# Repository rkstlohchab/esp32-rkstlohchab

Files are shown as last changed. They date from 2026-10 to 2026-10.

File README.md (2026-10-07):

# esp32-rkstlohchab

ESP32-S3 N16R8 handheld wireless toolkit by **rkstlohchab**, with a TPM408-2.8 touchscreen, KY-023 joystick, Wi-Fi/BLE, and external radio, NFC, GPS and IR modules.

This repository contains the current firmware, the wiring used by this build, and the revision-2 enclosure. The firmware keeps its `ESP32-DIV/` sketch directory and internal compatibility identifiers. The visible branding is `rkstlohchab`.

## Start here

| I want to… | Open |
|---|---|
| See the wiring / final connection schematic | [Hardware guide](hardware/README.md) · [illustrated PNG](hardware/wiring-poster.png) · [zoomable SVG](hardware/wiring-poster.svg) |
| Split shared pins on a breadboard / wire direct jumpers | [Breadboard and direct wiring](hardware/BREADBOARD.md) |
| Get the component list | [Bill of materials](hardware/components.csv) |
| Look up a GPIO | [Pin map CSV](hardware/pin-map.csv) |
| Build or flash firmware | [Build and flash guide](docs/BUILD.md) |
| Download the compiled firmware | [Firmware files and checksums](firmware/README.md) |
| Print the case | [Enclosure guide](enclosure/README.md) · [download ZIP](enclosure/enclosure-v2.zip) |
| Explore the 3D assembly | [Interactive viewer](enclosure/enclosure.html) · [layout drawing](enclosure/layout-v2.png) |
| Avoid the assembly mistakes we encountered | [Mistakes and fixes, including PN532 mode switches](docs/ASSEMBLY-MISTAKES.md) |
| Check what has actually been tested | [Status and limitations](docs/STATUS.md) |
| Find the source | [Arduino sketch](ESP32-DIV/ESP32-DIV.ino) · [board pin configuration](ESP32-DIV/BoardConfig.h) |
| Apply the required display patches | [TFT_eSPI patch](tft_espi-patch/README.md) |

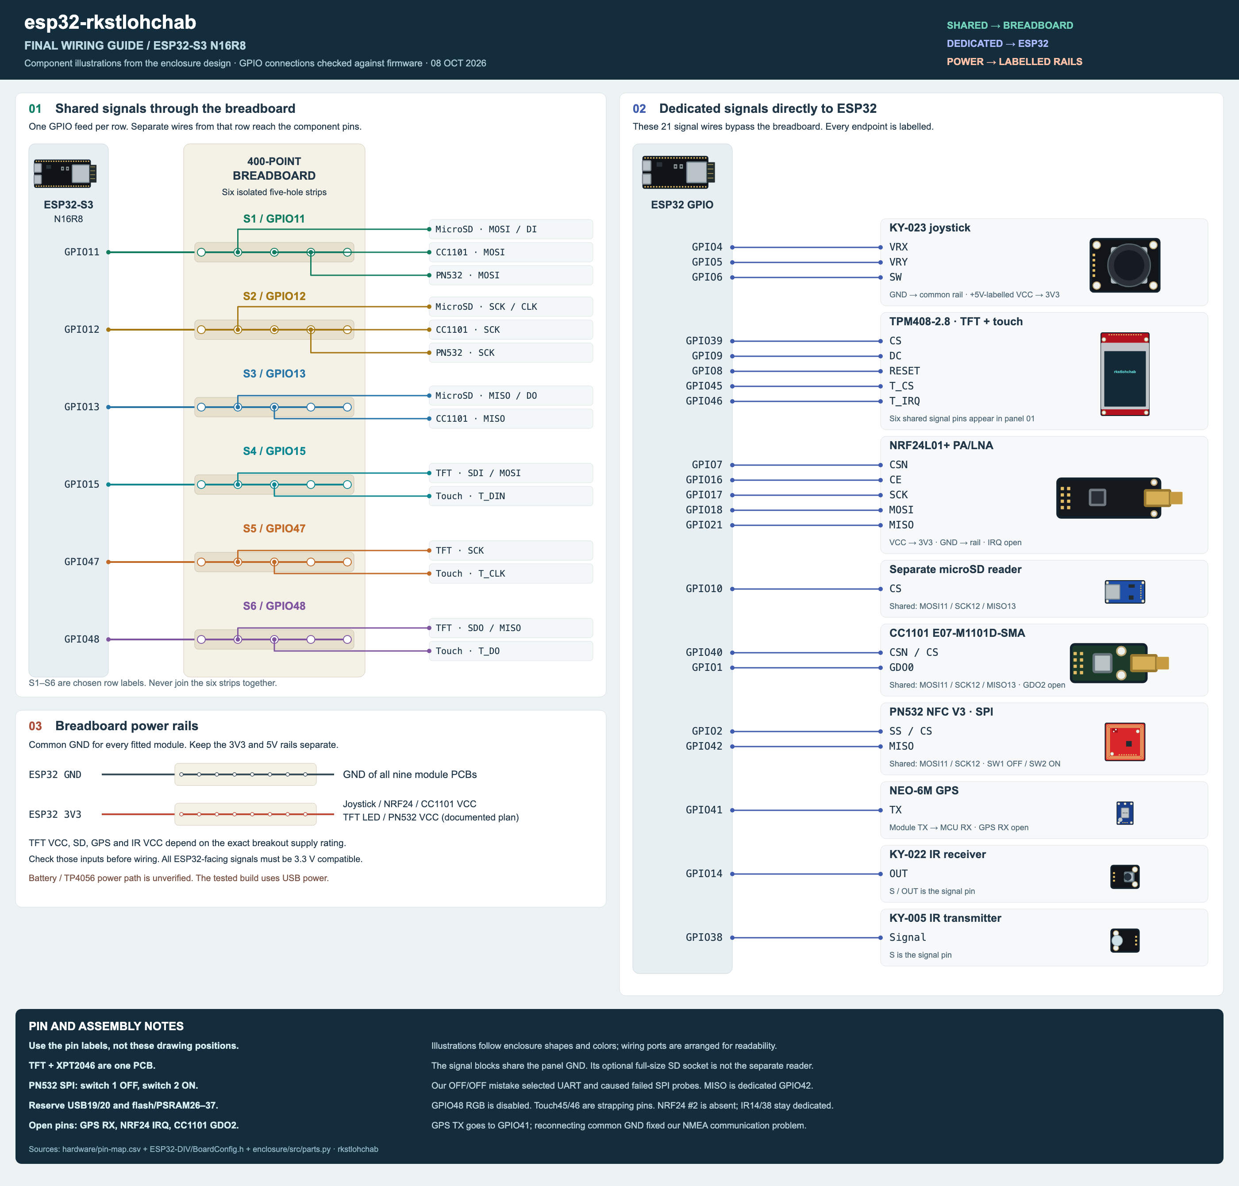
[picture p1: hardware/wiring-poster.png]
Illustrated wiring guide: shared breadboard nets and direct ESP32 pins


[Download full-resolution PNG](hardware/wiring-poster.png) · [Zoomable SVG](hardware/wiring-poster.svg) · [Detailed connection schematic](hardware/wiring.svg)

## Use the device

1. Wire the board using the [current hardware guide](hardware/README.md).
2. Flash the N16R8 firmware using the [build and flash guide](docs/BUILD.md).
3. Boot normally for the primary UI. Hold the joystick click while resetting, then release, for the alternate full-screen UI. Restart to switch modes.
4. Use the joystick to navigate; touch calibration is available in the primary UI.

The latest branded build compiles at **2,724,621 bytes (86% of the 3 MB app slot)** and **159,604 bytes of static RAM (48%)**. It has not been flashed or hardware-tested in this documentation update. Earlier hardware results are recorded separately in [status](docs/STATUS.md).

## 3D enclosure

Revision 2 is **96.4 × 168.4 × 94.0 mm** (width × height × depth), excluding antennas and joystick projection. It includes clearance for breadboard jumper housings and loose wire bays.

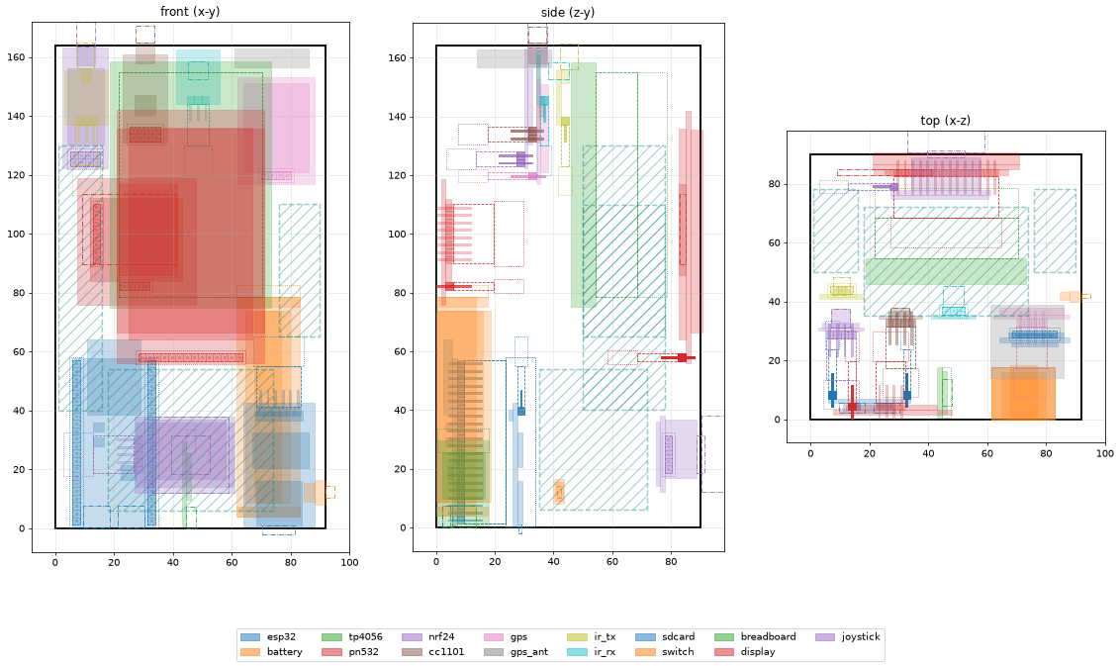
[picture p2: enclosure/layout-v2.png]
Revision-2 enclosure layout


- [Back tub STL](enclosure/stl/enclosure_back_tub.stl)
- [Front plate STL](enclosure/stl/enclosure_front_plate.stl)
- [Parametric source and rebuild instructions](enclosure/README.md)

The enclosure passes digital collision and solid checks; it has **not been physically print-tested**. Battery/charger/switch pockets are mechanical provisions. The verified electrical build runs on USB with the battery circuit disconnected.

## Repository map

```text
ESP32-DIV/          Arduino firmware and board-specific GPIO configuration
hardware/           Current wiring, component list, pin map and diagram generator
enclosure/          Revision-2 STL files, 3D viewer, layout and parametric source
firmware/           Current N16R8 binaries and SHA-256 checksums
docs/               Build guide, status and local documentation entry page
tft_espi-patch/     Required TPM408 display configuration and rotation patch
Libraries/          Upstream library archives; see build guide before using
PCB/, Schematic/   Legacy upstream PCB designs, not this breadboard build
licenses/           Notices for incorporated third-party code
```

The files `PORT.md`, `MERGE.md`, and `MARAUDER-UI-FIX.md` are historical development notes. Start with the current guides above: older notes contain earlier pin assignments and build sizes. Legacy bundled binaries and the old upstream web flasher are excluded from this clean repository snapshot.

## License and acknowledgments

This project incorporates ESP32-DIV and ESP32 Marauder code. Required upstream MIT notices are preserved in [LICENSE](LICENSE) and [licenses/ESP32Marauder-MIT.txt](licenses/ESP32Marauder-MIT.txt). Branding changes do not change those notices. Use wireless testing features only on equipment and networks you own or have permission to test.

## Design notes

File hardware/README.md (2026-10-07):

# Current hardware and wiring

Snapshot: **2026-10-08**. Electrical pin assignments come from [`ESP32-DIV/BoardConfig.h`](../ESP32-DIV/BoardConfig.h), checked against the configured display patch and the latest local bring-up notes. This is the final documented **module connection schematic for the current bench configuration**, not a new custom PCB design.

- [Illustrated wiring image (PNG)](wiring-poster.png) · [zoomable SVG](wiring-poster.svg)
- [Detailed connection schematic](wiring.svg)
- [Breadboard shared rows and direct jumpers](BREADBOARD.md)
- [Machine-readable pin map](pin-map.csv)
- [Component list / bill of materials](components.csv)
- [3D enclosure and assembly](../enclosure/README.md)
- [Verification record](../docs/STATUS.md)

Illustrated wiring guide

## Signal connections

| Module | Module pins → ESP32-S3 GPIO |
|---|---|
| KY-023 joystick | VRX → 4; VRY → 5; SW → 6 |
| ILI9341 TFT | SDI/MOSI → 15; SCK → 47; SDO/MISO → 48; CS → 39; DC → 9; RESET → 8 |
| XPT2046 touch | T_DIN → 15; T_CLK → 47; T_DO → 48; T_CS → 45; T_IRQ → 46 |
| NRF24L01+ (one radio) | CSN → 7; CE → 16; SCK → 17; MOSI → 18; MISO → 21; IRQ unconnected |
| Separate microSD reader | CS → 10; MOSI/DI → 11; SCK/CLK → 12; MISO/DO → 13 |
| CC1101 | CS → 40; MOSI → 11; SCK → 12; MISO → 13; GDO0 → 1; GDO2 unconnected |
| PN532 in SPI mode | SS/CS → 2; MOSI → 11; SCK → 12; MISO → 42; SDA/SCL not used |
| GPS NEO-6M | TX → 41; RX unconnected; UART 9600 baud |
| IR receiver | OUT → 14 |
| IR transmitter | Signal → 38 |

Touch IRQ is wired but touch is polled. The GPS TX output connects to the MCU's RX input; `GPS_UART_TX=0` is an unused firmware placeholder, **not a connection to make**. Likewise, `CC1101_GDO2=1` is a software alias for the single GDO0 data path; it does not mean physically join GDO2 to GPIO1.

## SPI wiring groups

| Group | SCK | MOSI | MISO | Individual selects |
|---|---|---|---|---|
| Display + touch | 47 | 15 | 48 | TFT 39; touch 45 |
| Storage / SubGHz | 12 | 11 | 13 | SD 10; CC1101 40 |
| PN532 software SPI | 12 (shared) | 11 (shared) | **42 (dedicated)** | PN532 2 |
| NRF24 wiring | 17 | 18 | 21 | CSN 7; CE 16 |

These are wiring groups, not a claim of four independent hardware SPI controllers. Firmware reclaims shared SPI resources when changing features. Never join PN532 MISO42 to the storage MISO13 net. Modules sharing clock/MOSI need their own chip selects, with inactive devices deselected.

## Power connections

The current tested build is **USB powered**. Distribute supply and GND using breadboard rails; all module grounds connect to ESP32 GND.

| Module | Power connection / constraint |
|---|---|
| Joystick | VCC pin marked `+5V` is connected to **3V3** so VRX/VRY stay within ESP32 input levels |
| TFT backlight LED | **3V3**, hardwired; no MCU backlight PWM pin |
| NRF24L01+ | **3V3 only**; 10–47 µF capacitor close to VCC/GND |
| CC1101 | **3V3**, with common GND |
| PN532 V3 | 3V3 supply in the documented plan; SPI switch mode on the tested module: SW1 OFF, SW2 ON |
| TFT module VCC, SD reader, GPS, IR modules | Check the exact breakout's regulator and supply rating. All MCU-facing signals must be 3.3 V compatible. The notes do not establish one universal VCC for every breakout variant |

The SD reader's VCC depends on its regulator and level shifting; use 5 V only for a breakout designed for that input. A bare 3.3 V card interface needs 3V3. Do not infer VCC from the signal wiring diagram.

The 18650, TP4056 and power switch are present in the **mechanical** design but were disconnected in the latest electrical checks. There is no verified battery-to-ESP32 regulated power schematic in this project. Do not connect a Li-ion cell directly to 3V3 or assume the case's battery pocket defines a complete power circuit.

## Pins intentionally unavailable or unconnected

- GPIO19/20 are reserved for native USB.
- GPIO26–32 and GPIO33–37 are reserved by flash and octal PSRAM on this N16R8 configuration.
- GPIO48 is display MISO; firmware disables the onboard RGB LED.
- GPIO0 is BOOT; leave GPS RX disconnected rather than wiring the unused TX placeholder.
- GPIO45/46 are boot strapping pins used by this existing touch wiring. Preserve the tested reset levels; do not treat them as generic extra outputs.
- NRF24 radios #2/#3, buzzer, PCF8574, and battery ADC are not fitted/enabled. NRF24 #2 placeholders overlap IR14/38 and must be reassigned before adding that radio.
- NRF24 IRQ and CC1101 GDO2 remain open.

GPIO numbers are signal labels, not physical header positions. Match the printed GPIO labels on your exact DevKit board. Legacy `PCB/` and `Schematic/` files describe upstream boards and do not override this pin map.

## Rebuild the pin diagram

```sh
python3 hardware/generate_wiring.py
```

The generator reads `pin-map.csv`, checks every GPIO against the board configuration, and writes `wiring.svg`. Update the firmware configuration and CSV together when wiring changes.

See [assembly mistakes and fixes](../docs/ASSEMBLY-MISTAKES.md), especially the PN532 mode switches and GPS common ground.

## Illustrated image and component models

The [final PNG](wiring-poster.png) combines component illustrations derived from `enclosure/src/parts.py` with the verified CSV connections. Its left panel shows six ESP32 feeds into six breadboard strips and individual component branches. Its right panel shows all 21 dedicated signal connections. They describe the same ESP32 and modules, separated into two panels for readable wire paths.

Module illustrations identify the parts and their proportions. Wires terminate at labelled schematic ports; follow your actual PCB silkscreen rather than treating illustration positions as a header locator. TFT and touch share one physical PCB. Power inputs whose breakout supply rating has not been established are explicitly marked for verification.

Regenerate both formats (PNG export requires Chrome/Chromium):

```sh
python3 hardware/generate_wiring_poster.py --png
```

Omit `--png` to regenerate the editable SVG without a browser.

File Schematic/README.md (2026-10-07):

# Legacy upstream Schematic files

These assets are retained as design references for the original upstream boards. They are **not the final schematic or PCB for this ESP32-S3 N16R8 breadboard build**.

Use the [current hardware wiring](../hardware/README.md), [pin map](../hardware/pin-map.csv), and [revision-2 enclosure](../enclosure/README.md).

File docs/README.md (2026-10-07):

# Documentation

- [Final illustrated wiring image](../hardware/wiring-poster.png) · [zoomable version](../hardware/wiring-poster.svg)
- [Current hardware schematic and connections](../hardware/README.md)
- [Breadboard shared pins and direct ESP32 jumpers](../hardware/BREADBOARD.md)
- [Component list](../hardware/components.csv)
- [GPIO pin map](../hardware/pin-map.csv)
- [Build and flash](BUILD.md)
- [Verification and limitations](STATUS.md)
- [3D design, assembly and printing](../enclosure/README.md)
- [Firmware downloads](../firmware/README.md)

To open the interactive 3D assembly, run `python3 -m http.server 8000` from the repository root and visit `http://localhost:8000/enclosure/enclosure.html`. The viewer currently loads Three.js and fonts from CDNs, so internet access is needed. GitHub's file preview displays the HTML source rather than running the viewer.

`PORT.md`, `MERGE.md`, and `MARAUDER-UI-FIX.md` at the repository root are retained as historical notes, not the current wiring reference.

See [assembly mistakes and fixes](../docs/ASSEMBLY-MISTAKES.md), especially the PN532 mode switches and GPS common ground.

The interactive enclosure HTML is committed under `enclosure/enclosure.html`. GitHub Pages is not configured; the repository file link shows source, and the local server instructions above run the viewer.

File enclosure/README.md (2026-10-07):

# Enclosure revision 2 — jumper wire space

**Outer size: 96.4 × 168.4 × 94.0 mm (width × height × depth).**
Internal cavity: 92 × 164 × 90 mm. Previous case: 62.4 × 128.4 × 66 mm.
Dimensions exclude antennas and the projecting joystick cap.

This revision retains the 400-point breadboard and allows Dupont connectors
on all header modules, including NRF24, CC1101, GPS and IR. The original
solder-only assumption for those modules has been removed. This repository distributes revision 2 only.

## Files

| File | Use |
|---|---|
| `stl/enclosure_back_tub.stl` | Print back down; support the SD shelf above the battery |
| `stl/enclosure_front_plate.stl` | Print face down |
| `enclosure.html` | Interactive assembly, exploded view, drawings and STL downloads |
| `layout-v2.png` | Orthographic views; hatched areas reserve loose wire space |
| `layout.json` | Dimensions, placements, openings and wire budget |
| `build.py`, `src/` | Parametric design and clearance checks |

## Space for your wires

The design assumes **60 individual 20 cm wires plus five individual 40 cm
wires**, with insulation up to 2 mm diameter: 14 metres total.
At 30% wire / 70% free air, the estimated loose-wire volume is **146.6 cm³**.
Three dedicated bays provide **154.9 cm³**, in addition to connector and bend
envelopes. This is a packing estimate, not a simulated routed harness;
thicker wires, ribbon bundles or extra modules need more space.

| Reserved region | Clear size | Volume |
|---|---|---|
| Lower service-loop bay | 56 × 48 × 37 mm | 99.5 cm³ |
| Left routing corridor | 15 × 90 × 28 mm | 37.8 cm³ |
| Right routing corridor | 14 × 45 × 28 mm | 17.6 cm³ |

Each header allows **14 mm female housings plus 10 mm free space after the
housing**. Straight connectors also include their male header spacer.
The breadboard has a 24 mm plug-and-bend zone above its 8.5 mm body.
The PN532 model reserves both header banks, including SPI.

Put surplus wire into broad, loose loops in the lower bay. Use the side
corridors for front connections. Keep the lid lip, screws, joystick mechanism,
display glass and GPS patch clear. Fit module plugs before installing the
breadboard. Leave service slack for lifting the front plate. The lid should
seat freely; its screws must not compress wire bundles.

## Battery pocket: 4 mm longer

Nominal holder: 74.5 × 21.5 mm. Cell: 65 mm long, unchanged.
The end stop moves **4.0 mm**, giving **78.9 mm clear length**
(74.5 + 4.0 + 0.4 mm fit allowance). Two side rails give **21.9 mm clear width**.
The extra length is reserved in the collision model. Add a removable foam
shim if the existing shorter holder slides.

## Layout and ports

Breadboard underside: 46 mm above the inside back face. Jumper bend space
ends at 78.5 mm. Display PCB: 85 mm. The lower section holds the wire loops.
The display and joystick are centred on the removable front plate.

USB-C and microSD access remain on the bottom; SMA and IR openings are on top;
the switch is on the right. The back has the NFC target and BOOT/RST pinholes.
Use the **separate microSD reader**: the display's optional full-size SD socket
is now internal only.

PN532 uses SPI: switch 1 away from ON, switch 2 toward ON.
SCK → GPIO12, MOSI → GPIO11, MISO → GPIO42, SS → GPIO2.
SDA/SCL are not used in this mode. Viewer colors are suggested labels,
not a record of installed wire colors.

## Printing and assembly

Starting settings: 0.4 mm nozzle, 0.20 mm layers, 4 perimeters, 25% infill,
PLA or PETG. Inspect the slicer preview. The back tub's broad SD shelf needs
removable support beneath it; remove support before fitting the battery.
Other overhangs depend on your printer. STLs are already oriented on z=0.

Hardware: 4 × M2.5 × 8 countersunk lid screws, 4 × M3 × 6 display screws,
2 × M3 × 8 joystick screws, removable tape/foam for parts without screw mounts.
Print the front plate first to check the display and joystick fit.

1. Remove supports. Fit ESP32. Fit the TP4056 and holder mechanically if desired; keep the unverified battery circuit disconnected.
2. Fit PN532 on its pegs, GPS on its posts and patch beneath the top wall.
3. Fit radios, IR boards, microSD and switch. Connect their jumpers.
   Tape/foam secures boards without dedicated screw mounts.
4. Tape the breadboard onto its side ledges. Arrange loose wires in the lower
   bay and side corridors before fitting front connections.
5. Mount display and joystick on the plate, connect them, and lower the plate
   while watching the wiring. Close with four lid screws only when it seats freely.

## Verification and limits

The build rejects module/wall conflicts, printed solids blocking modules,
connectors, bends or reserved wire bays, shell mating interference, and
insufficient wire volume. PN532/GPS mounting holes are excluded from their
coarse boxes so the pegs can pass through. Both meshes must be valid connected
solids. Revision 2 passes these checks with **zero conflicts**.

This is digitally checked, not physically print-tested. Joystick and IR sizes
include estimates; several modules use listing dimensions and photo-derived
positions. Check your board variants, connector heights and holder dimensions.
The design includes the 15 parts listed in `layout.json`. A separate boost
converter has no dedicated mount or assumed footprint in this revision.

## Rebuild

```sh
pip install manifold3d numpy matplotlib
python3 build.py
python3 src/layout.py layout-v2.png
```

Parts: `src/parts.py`; placements and wire budget: `src/layout.py`;
printed mounts: `src/shell.py`. Rebuilding updates the STLs and viewer together.

## Electrical reference

Use the [current hardware guide](../hardware/README.md) for electrical connections. Battery, charger and switch models are mechanical provisions; the verified build is USB powered.

The [illustrated wiring guide](../hardware/wiring-poster.png) uses these component models together with the firmware pin map. See the [editable wiring SVG](../hardware/wiring-poster.svg) for a zoomable version.

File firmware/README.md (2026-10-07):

# Current N16R8 firmware

Built 2026-10-08 from the branded source in this snapshot, using ESP32 core 2.0.10 and the settings in the [build guide](../docs/BUILD.md).

| File | Flash offset | Purpose |
|---|---|---|
| [ESP32-DIV.ino.bootloader.bin](ESP32-DIV.ino.bootloader.bin) | 0x0000 | ESP32-S3 bootloader |
| [ESP32-DIV.ino.partitions.bin](ESP32-DIV.ino.partitions.bin) | 0x8000 | 16 MB flash partition table, two 3 MB app slots |
| [boot_app0.bin](boot_app0.bin) | 0xe000 | Initial OTA selection data |
| [ESP32-DIV.ino.bin](ESP32-DIV.ino.bin) | 0x10000 | Application |

[SHA-256 checksums](SHA256SUMS.txt). Verify from this directory with `shasum -a 256 -c SHA256SUMS.txt` (macOS) or `sha256sum -c SHA256SUMS.txt` (Linux).

Application: 2,724,621 bytes (86% of slot). Static RAM: 159,604 bytes (48%). Compile and a host frame-bounds check passed; this exact branded snapshot has **not been flashed or hardware-tested**. These binaries target the documented N16R8 configuration, not stock ESP32-DIV PCB variants.

See the [complete flash command](../docs/BUILD.md#flash-precompiled-binaries); the application binary alone is not the first-flash package.

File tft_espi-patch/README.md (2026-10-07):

# TFT_eSPI patch for this build

The firmware only displays correctly with these two files dropped into the
Arduino **TFT_eSPI 2.5.43** library (`~/Documents/Arduino/libraries/TFT_eSPI/`),
overwriting the originals:

| File | Why |
|---|---|
| `User_Setup.h` | Pins for the dedicated display bus (MOSI 15, SCLK 47, MISO 48, CS 39, DC 9, RST 8, touch CS 45), `ILI9341_NATIVE_LANDSCAPE_PANEL`, and `TFT_RGB_ORDER TFT_RGB` |
| `TFT_Drivers/ILI9341_Rotation.h` | Axis-swapped rotations for the TPM408-2.8 panel, whose glass is scanned 320x240 |

Without them the UI draws rotated 90° with 80 rows of noise, and red/blue are
swapped. After copying, delete the build cache's `libraries/TFT_eSPI` folder
so the headers are recompiled.

Re-apply after any TFT_eSPI update or reinstall.

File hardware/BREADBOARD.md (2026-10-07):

# Breadboard sharing and direct ESP32 jumpers

Use this alongside the [complete pin diagram with actual ESP32 → breadboard → component paths](wiring.svg) and [hardware power notes](README.md#power-connections). The firmware determines which wires share a net; the breadboard rows below are a suggested physical layout, not a record of exact numbered rows in the assembled prototype.

## Shared signal pins: split these on the breadboard

Run **one jumper from the ESP32 GPIO to its own connected five-hole breadboard row**, then connect each listed module pin to that same row. Use a different isolated row for each GPIO. On a typical breadboard, the two five-hole groups on opposite sides of the centre gap are not connected. Bridge only if you deliberately need the other side.

| Suggested isolated row | ESP32 GPIO → row | Module pins connected to that same row |
|---|---|---|
| S1 | GPIO**11** | MicroSD **MOSI / DI**; CC1101 **MOSI**; PN532 **MOSI** |
| S2 | GPIO**12** | MicroSD **SCK / CLK**; CC1101 **SCK**; PN532 **SCK** |
| S3 | GPIO**13** | MicroSD **MISO / DO**; CC1101 **MISO** |
| S4 | GPIO**15** | TFT ILI9341 **SDI / MOSI**; Touch XPT2046 **T_DIN** |
| S5 | GPIO**47** | TFT ILI9341 **SCK**; Touch XPT2046 **T_CLK** |
| S6 | GPIO**48** | TFT ILI9341 **SDO / MISO**; Touch XPT2046 **T_DO** |

S1–S6 are labels you choose, not mandatory printed row numbers. Each is an independent electrical net. Keep signal wires short, especially SPI clock and data.

Shared breadboard nets

**Do not combine all MOSI or all MISO pins into one row.** Display MOSI15 and storage MOSI11 are separate nets; display MISO48, storage MISO13, PN532 MISO42 and NRF24 MISO21 are all separate. NRF24 SCK17/MOSI18/MISO21 each go only to that radio in this build.

## Dedicated signals: one direct jumper to the ESP32

These have one module endpoint in the current fitted configuration. They can connect directly to the GPIO-labelled ESP32 header, without a breadboard split. Routing one through an isolated breadboard row is electrically equivalent if it makes assembly easier.

| Module | Direct ESP32 GPIO ↔ module pin |
|---|---|
| Joystick | GPIO**4** ↔ **VRX**; GPIO**5** ↔ **VRY**; GPIO**6** ↔ **SW** |
| TFT ILI9341 | GPIO**39** ↔ **CS**; GPIO**9** ↔ **DC**; GPIO**8** ↔ **RESET** |
| Touch XPT2046 | GPIO**45** ↔ **T_CS**; GPIO**46** ↔ **T_IRQ** |
| NRF24L01+ | GPIO**7** ↔ **CSN**; GPIO**16** ↔ **CE**; GPIO**17** ↔ **SCK**; GPIO**18** ↔ **MOSI**; GPIO**21** ↔ **MISO** |
| MicroSD | GPIO**10** ↔ **CS** |
| CC1101 | GPIO**40** ↔ **CS**; GPIO**1** ↔ **GDO0** |
| PN532 | GPIO**2** ↔ **SS / CS**; GPIO**42** ↔ **MISO** |
| GPS NEO-6M | GPIO**41** ↔ **TX** |
| IR receiver | GPIO**14** ↔ **OUT** |
| IR transmitter | GPIO**38** ↔ **Signal** |

The KY-023 VRX4/VRY5/SW6 connections are documented as direct to the ESP32 in the existing build notes. For the other dedicated signals, this table describes the direct jumper wiring supported by the current pin assignments; the notes do not establish every jumper's actual physical routing.

GPIO45/46 are strapping pins in the tested touch wiring; preserve the current reset levels. IR14/38 are dedicated only while NRF24 #2 is absent. Do not install the second radio on those placeholder assignments.

## Power: use the common breadboard rails

- ESP32 **GND → ground rail**; each fitted module's GND → that same rail.
- ESP32 **3V3 → a labelled 3V3 rail**; connect only modules/inputs requiring 3.3 V to it. Joystick `+5V` silkscreen is supplied from **3V3** in this build.
- TFT backlight LED → 3V3 rail. NRF24 VCC → 3V3 rail, with its capacitor directly across local VCC/GND.
- If an exact breakout needs a 5 V input, use a separate labelled **5 V rail** after checking its rating and signal compatibility. **Never bridge 3V3 and 5 V rails.** See [module-specific supply constraints](README.md#power-connections).
- Many breadboard power rails are split halfway along their length. Check continuity and bridge matching rail segments only when needed.

Power off before changing jumpers. Do not push multiple Dupont connectors onto one ESP32 header pin; split shared nets on the breadboard instead. The battery circuit stays disconnected until a regulated power path has been specified and tested.

## Leave these unconnected

NRF24 IRQ, CC1101 GDO2, GPS RX, all unfitted second/third radio connections, and disabled buzzer/battery-ADC placeholders. All module grounds still need the common GND rail.

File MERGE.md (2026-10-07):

# ESP32-DIV + Marauder — merged firmware

A copy of the ESP32-DIV N16R8 port (`esp32-div/`) with **ESP32Marauder embedded as
a headless serial-CLI subsystem**. DIV keeps its full display UI and its own features
(WiFi/BLE UI, SubGHz, NFC, IR, GPS); Marauder adds its deeper WiFi/BLE/GPS engine,
reachable over the USB serial CLI.

**Status: FULL-UI merge — compiles (71%), normal boot verified on hardware (2026-09-21).**
Marauder now runs with its COMPLETE native touch UI (116 screens), not a CLI.
DIV boots clean (banner, SD, BLE init, PCF/joystick nav, no crash, single boot).
Marauder CLI is live over serial: `help` returns the full command set, and a real
`scanall` found local APs with RSSI/channel/BSSID *and* station-to-AP relationships;
`stopscan` and `list -a` work. No panics or boot loops.

- Merged app size: **2,239,885 bytes (71%** of a 3 MB app partition, full UI)
- RAM: 155,572 bytes static (47%)
- **Zero symbol collisions** between the two codebases.

## How the merge works

The blocker with a "real" merge is that Marauder's WiFi engine (`WiFiScan.cpp`,
12,789 lines) has **923 references to Marauder's own `Display` object** — its engine
is inseparable from its UI. Merging two display UIs onto one screen is not feasible.

The solution: Marauder's own full touch UI is re-enabled by targeting its
`MARAUDER_MULTIBOARD_S3` board (an ESP32-S3 + ILI9341) and grafting the ILI9341
320x240 UI-layout constants (from Marauder's `MARAUDER_V4` blocks) onto it, since the
stock S3 target ships headless. Both DIV and Marauder drive the SAME ILI9341 through
TFT_eSPI's one `User_Setup.h`, and both read touch via `tft.getTouch()` — so they
share the display + touch layer cleanly.

**Two modes, selected at boot** (no dual-UI-on-one-screen conflict):
- Normal power-on -> **ESP32-DIV** (its UI + SubGHz/NFC/IR + its own WiFi/BLE).
- **Hold the joystick click at power-on -> Marauder's full touch UI** (all 116
  screens: WiFi/BLE attacks, scans, evil portal, wardrive, etc.). Reboot to switch.

The engine lives under `ESP32-DIV/src/marauder/`; `marauder_setup()/marauder_loop()`
are invoked exclusively when the joystick launches Marauder mode.

## What was changed (all in the copy, originals untouched)

1. **`ESP32-DIV/src/marauder/`** — all 83 Marauder source files, plus:
   - `configs.h`: `#define GENERIC_ESP32` enabled (headless: WiFi + BT, no screen)
   - `marauder_app.cpp`: Marauder's `.ino`, with `setup()/loop()` renamed to
     `marauder_setup()/marauder_loop()`, and the `while(!Serial)` boot-wait bounded
     to 1.5 s so it never blocks on battery.
   - `marauder_app.h`: exposes those two entry points.
2. **`ESP32-DIV/ESP32-DIV.ino`** — includes `src/marauder/marauder_app.h`, calls
   `marauder_setup()` at the end of `setup()` and `marauder_loop()` at the top of
   `loop()`. So Marauder's CLI runs alongside DIV's UI.
3. **Partition scheme → Huge APP (3 MB + 1 MB SPIFFS), no OTA.** Marauder stores its
   settings in **SPIFFS**, which the FAT partition scheme lacks. Huge APP provides
   SPIFFS and still fits the 2 MB merged app. (Trade-off: no OTA on this build.)

## Build settings (Arduino IDE)

Same as the DIV port EXCEPT the partition scheme:

| Setting | Value |
|---|---|
| Board | ESP32S3 Dev Module |
| PSRAM | OPI PSRAM |
| Flash Size | 16MB (128Mb) |
| **Partition Scheme** | **Huge APP (3MB No OTA/1MB SPIFFS)** |
| USB CDC On Boot | Enabled |
| Flash Mode | QIO 80MHz |
| CPU | 240MHz |

FQBN: `esp32:esp32:esp32s3:PSRAM=opi,FlashSize=16M,PartitionScheme=huge_app,CDCOnBoot=cdc,FlashMode=qio,CPUFreq=240,USBMode=hwcdc`

## Libraries added for Marauder (DIV's shared deps kept per instruction)

Installed alongside DIV's set; where shared (NimBLE, TFT_eSPI, ArduinoJson) DIV's
versions were kept:

| Library | Version | For |
|---|---|---|
| LinkedList | (Marauder submodule) | Marauder data structures |
| Adafruit NeoPixel | 1.15.5 | LED (guarded off headless) |
| MicroNMEA | 2.0.6 | GPS parsing |
| EspSoftwareSerial | 8.1.0 | GPS soft-serial |
| ESP32Ping | (github marian-craciunescu) | network ping scan |
| Async TCP | 3.5.0 | Evil Portal async server |
| ESP Async WebServer | 3.12.1 | Evil Portal |

Note: Async TCP 3.x and ESP Async WebServer 3.x MUST be paired (the old me-no-dev
1.1.4 AsyncTCP fails to compile against WebServer 3.x).

## How to use once flashed

- **DIV's UI** works as before on the display (needs the 2.8" ILI9341).
- **Marauder's CLI** is live over USB serial at 115200. Open the Serial Monitor and
  type `help` for the full command list — `scanall`, `attack -t deauth`, `sniffraw`,
  `blespam`, `evilportal`, `wardrive`, `list`, `select`, etc.

## Verified on hardware / remaining caveats

Resolved by the boot+scan test: boots clean, Marauder WiFi engine actually scans, no
crash. Still worth knowing:
1. **Double WiFi init** — both DIV and Marauder init WiFi. Should be fine if only one
   drives the radio at a time, but a DIV WiFi feature + a Marauder scan at once could
   conflict.
2. **RAM under load** — 47% static; running a heavy Marauder scan *and* DIV together
   could get tight.
3. **Serial contention** — DIV's "Serial Monitor" tool and Marauder's CLI both read
   serial; avoid using both at once.
4. **Boot time** — `marauder_setup()` adds WiFi + SPIFFS init before DIV's UI appears.

If any of these misbehave, the fallback is **lazy activation**: gate `marauder_setup()`
behind a DIV menu entry so Marauder only initializes when you enter its mode.

## Revert

This whole thing is a copy — `esp32-div/` (DIV-only) is untouched. Delete
`esp32-div-marauder/` to discard the merge entirely.

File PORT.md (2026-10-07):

# ESP32-DIV — port to ESP32-S3 DevKitC-1 N16R8

Upstream ESP32-DIV **V2** targets an **ESP32-S3-WROOM-1U-N16** (confirmed in
`Schematic/v2/main-BOM.xls`): 16 MB flash, **no PSRAM**. With no PSRAM die in the
module, GPIO 33–37 are free, so upstream routes the display + touch bus there.

This board is an **ESP32-S3 N16R8**: 16 MB flash **plus 8 MB octal PSRAM**. Octal
PSRAM is bonded to GPIO 33–37 *inside the module*, so those pins cannot be used as
GPIO while PSRAM is enabled. The port moves the display bus off those pins and keeps
the full 8 MB PSRAM.

**Status: RUNNING on hardware with display + touch + joystick (2026-09-24).** The
TPM408-2.8 panel renders portrait, touch is calibrated, and the joystick drives the
menus. Firmware ~2.76 MB (87% of the 3 MB app partition) with the built-in IR
database. Display wiring and quirks are documented in `tft_espi-patch/` and the
project memory; see the pin map below for the current schema.

---

## Build settings (Arduino IDE)

Board: **ESP32S3 Dev Module**

| Setting | Value |
|---|---|
| USB CDC On Boot | **Enabled** — the DevKit has no CP2102; serial rides native USB |
| PSRAM | **OPI PSRAM** |
| Flash Size | 16MB (128Mb) |
| Flash Mode | QIO 80MHz |
| Partition Scheme | 16M Flash (3MB APP/9.9MB FATFS) |
| CPU Frequency | 240MHz |
| Upload Speed | 921600 |
| USB Mode | Hardware CDC and JTAG |

Open `esp32-div/ESP32-DIV/ESP32-DIV.ino`. `BoardConfig.h` already selects this board.

Verified via arduino-cli with:
`esp32:esp32:esp32s3:PSRAM=opi,FlashSize=16M,PartitionScheme=app3M_fat9M_16MB,CDCOnBoot=cdc,FlashMode=qio,CPUFreq=240,USBMode=hwcdc`

---

## What was changed, and why

The design goal was **all board differences in one place**. Every pin in
`shared.h` is `#ifndef`-guarded, so `BoardConfig.h` overrides them without touching
upstream sources. Upstream files carry only two tiny, marked edits; every original
is saved next to it as `.upstream`/`.orig`/`.stock`.

### 1. `ESP32-DIV/BoardConfig.h` — rewritten (upstream saved as `.upstream`)
The whole port lives here: joystick nav, moved display/touch bus, verified NRF24
pins, PN532-over-SPI, and placeholder pins for unfitted modules. Fully commented.

### 2. `ESP32-DIV/NavInput.h` — new
`JoystickNav` implements the three methods the feature code calls on the PCF8574
(`begin` / `pinMode` / `digitalRead`) and maps the 5-way keypad onto the KY-023's
two ADC axes + click. `typedef … NavExpander` picks joystick or real PCF8574. No
feature file changes; the object is still called `pcf`.

### 3. `ESP32-DIV/shared.h` — 3 marked edits (upstream saved as `.upstream`)
- `#include "NavInput.h"` after `BoardConfig.h`.
- `SD_NO_CARD_DETECT` guard so a card-detect-less breakout skips the `SD_CD` read.
- `TFT_CS_PIN` / `TFT_DC_PIN` / `TFT_RST_PIN` made overridable.

### 4. `pcf` object type: `PCF8574` → `NavExpander`
Six declaration sites (`bleconfig.h`, `config.h`, `wificonfig.h`, `subconfig.h`,
`ducky.cpp`, `ESP32-DIV.ino`). `ESP32-DIV.ino` also guards `#include <PCF8574.h>`.

### 5. `TFT_eSPI/User_Setup.h` — display pins + speed (stock saved as `.div-v2-stock`)
MISO/MOSI/SCLK → the shared SD bus (13/11/12); CS/DC/RST → 39/40/41;
`SPI_FREQUENCY` 27 MHz → 20 MHz (those pins have the parasitic PSRAM die on them).

### 6. `SmartRC-CC1101-Driver-Lib` — two library bugs
- `ELECHOUSE_CC1101_SRC_JT_DRV.*` moved to `jamtool_unused/` — the library shipped
  two full copies of the class, colliding on every symbol. The sketch never uses
  the JT variant. (originals in that subfolder)
- `bool spi` → `static bool spi` in `ELECHOUSE_CC1101_SRC_DRV.cpp` — collided with
  TFT_eSPI's global `spi`. (original saved as `.orig`)

### 7. `~/Library/Arduino15/.../2.0.10/platform.local.txt` — new
Prepends `-zmuldefs` to the linker libs so the sketch's
`ieee80211_raw_frame_sanity_check()` override replaces the WiFi SDK's copy (raw
frame injection). This is exactly what upstream's bundled `platform.txt` does. An
overlay file, so the stock `platform.txt` is untouched; delete to revert.

---

## Library versions (pinned — newer majors break this code)

| Library | Version | Why pinned |
|---|---|---|
| esp32 core | 2.0.10 | ESP32-DIV target; 3.x changed the APIs |
| NimBLE-Arduino | 1.4.x | code uses `NimBLEAdvertisedDeviceCallbacks` (1.x API) |
| ArduinoJson | 6.21.x | code uses `StaticJsonDocument` (6.x API) |
| arduinoFFT | 1.6.x | code uses `arduinoFFT` type + `FFTSUB` (2.x renamed) |
| Adafruit PN532, IRremoteESP8266, rc-switch, XPT2046_Touchscreen | latest | fine |
| RF24, TFT_eSPI, SmartRC-CC1101 | bundled | from the repo |

---

## Pin map (this board)

Rewired 2026-09-23 onto a dedicated display bus (see `BoardConfig.h`, the source of
truth). **3V3 and GND are distributed through the breadboard**, so every module's
power comes off the breadboard rails, not the ESP32 directly.

### Connected and verified now

| GPIO | Function | Notes |
|---|---|---|
| 4 / 5 / 6 | Joystick VRX / VRY / SW | direct to ESP32; SW also = Marauder-boot hold |
| 15 | TFT SDI **+** touch T_DIN | shared display data-in (MOSI) |
| 47 | TFT SCK **+** touch T_CLK | shared display clock |
| 48 | TFT SDO **+** touch T_DO | shared display data-out (MISO) |
| 39 | TFT CS | USB-safe pin (moved off GPIO20) |
| 9 | TFT DC | |
| 8 | TFT RST | |
| 45 | Touch T_CS | rides the shared display bus |
| 46 | Touch T_IRQ | strap pin — pull to enter flash mode |
| 3V3 | Display backlight (LED) | LED tied directly to 3V3; GPIO42 is PN532 MISO |

GPIO 48 doubles as the onboard WS2812; it is disabled in firmware
(`BOARD_NO_STATUS_RGB`) because it is now the display MISO line.

**NRF24L01+ and CC1101 added 2026-09-24 — SPI verified** (boot self-test read the
CC1101 version register and the NRF24 chip-connected check, both OK):

| GPIO | Function | Notes |
|---|---|---|
| 7 / 16 / 17 / 18 / 21 | NRF24 CSN / CE / SCK / MOSI / MISO | own SPI bus; add a 10µF cap at the module |
| 12 / 11 / 13 | CC1101 SCK / MOSI / MISO | shares the (still empty) SD bus |
| 40 | CC1101 CS | PN532 has its own CS on GPIO2 |
| 1 | CC1101 GDO0 (SubGHz data) | single async data line for both RX and TX |

CC1101 **GDO2 is left unconnected** (not needed for OOK). Firmware points every
SubGHz data macro (`SUBGHZ_RX_PIN`, `SUBGHZ_TX_PIN`, `RX_PIN`, `TX_PIN`,
`CC1101_GDO0`, `CC1101_GDO2`) at GPIO1 to match this wiring. The unfitted 3rd
NRF24's placeholder pins were moved off GPIO1/2 to free UART0 pins 43/44.

### Newly connected, verification pending (2026-09-30)

| GPIO | Function | Test result |
|---|---|---|
| 10 / 11 / 12 / 13 | MicroSD CS / MOSI / SCLK / MISO | Reader wired; no card inserted, so no card probe or read/write test possible. The boot message `SD Card detected` is an assumption when no card-detect pin exists. |
| 2 / 11 / 12 / 42 | PN532 CS / MOSI / SCLK / MISO | SPI communication verified on 2026-10-05 after setting SW1 OFF / SW2 ON. Firmware query returned `0x32010607` (PN532 version 1.6) on two boots. Previously both switches were OFF (UART mode), explaining the failed SPI probes. MISO is dedicated GPIO42; card reading remains to be tested. |
| 41 | GPS UART RX (module TX) | Verified after connecting GPS GND to the shared ground bus: 7,799 bytes and 282 valid NMEA lines in 47 seconds at 9600 baud. Module RX is left open; firmware's TX placeholder is GPIO0. |
| 14 / 38 | IR RX / TX | Firmware assignments; electrical function not tested in this session. These pins overlap the unfitted NRF24 #2 placeholders. |

The 18650 and boost circuit are disconnected; the board was USB powered during
these checks. A temporary diagnostic also read CC1101 part `0x00`, version `0x14`,
NRF24 status `0x0E`, and changing joystick ADC values. The diagnostic was
replaced by the merged firmware with PN532 CS corrected to GPIO2, and that build
reached `[boot] ready` over USB serial.

### Conflicts to resolve before adding the overlapped parts

| Pins | Shared between |
|---|---|
| 38 | NRF24 #2 CSN **and** IR TX |
| 14 | NRF24 #2 CE **and** IR RX |

Free pins for reassigning: **3, 43, 44** (43/44 are the unused UART0 pins on this
native-USB board). Never use 19/20 (USB), 26–32 (flash), 33–37 (octal PSRAM).

The PN532 shares SPI clock GPIO12 and MOSI GPIO11 with the CC1101 and SD reader,
but now has dedicated MISO GPIO42 and CS GPIO2. CC1101 and SD continue sharing
MISO GPIO13 with separate CS pins 40 and 10.

---

## Rebuild / revert

Rebuild: open the sketch, apply the settings above, Upload. `platform.local.txt`
and the library edits persist in the Arduino folders.

Revert any piece:
```
# board config / shared.h
cp ESP32-DIV/BoardConfig.h.upstream ESP32-DIV/BoardConfig.h
cp ESP32-DIV/shared.h.upstream      ESP32-DIV/shared.h
# TFT display config
cp ~/Documents/Arduino/libraries/TFT_eSPI/User_Setup.h.div-v2-stock \
   ~/Documents/Arduino/libraries/TFT_eSPI/User_Setup.h
# CC1101 spi symbol
cp ~/Documents/Arduino/libraries/SmartRC-CC1101-Driver-Lib/ELECHOUSE_CC1101_SRC_DRV.cpp.orig \
   ~/Documents/Arduino/libraries/SmartRC-CC1101-Driver-Lib/ELECHOUSE_CC1101_SRC_DRV.cpp
# linker overlay
rm ~/Library/Arduino15/packages/esp32/hardware/esp32/2.0.10/platform.local.txt
```

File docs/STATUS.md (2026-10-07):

# Verification and current limits

Documentation snapshot: **2026-10-08**. Earlier observations below come from the local hardware bring-up notes; they were not all repeated in this update.

| Area | Evidence | Remaining work |
|---|---|---|
| Latest branded firmware | Arduino CLI build passes: 2,724,621 bytes (86% of app slot), 159,604 bytes static RAM (48%) | Flash and run this exact snapshot |
| Branding | Startup logos removed; splash/About/serial text uses `rkstlohchab`; scan export branding updated | Check on actual display |
| Deauther frame buffer | Existing Div implementation retained; write beyond byte 25 fixed; host frame check passed AddressSanitizer and UndefinedBehaviorSanitizer | No radio/deauthentication hardware test performed |
| Primary UI | Earlier normal boot, display, calibrated touch and joystick verified | Full feature regression |
| Alternate UI | User confirmed menu appears, joystick works, and row redraw remains steady after earlier fixes | Full screen/menu regression |
| NRF24 | Earlier chip-connected check and raw SPI register round-trips passed | RF range and feature testing |
| CC1101 | Earlier SPI part/version read passed (part 0x00, version 0x14) | End-to-end RF receive/transmit testing |
| PN532 | 2026-10-05 SPI firmware query returned 0x32010607 on two boots after selecting SPI mode | NFC tag read/write and supported tag variants |
| GPS | 7,799 bytes / 282 valid NMEA lines in 47 seconds at 9600 baud after common GND was connected | Outdoor satellite fix and logged coordinates |
| Separate microSD reader | Wired to CS10, MOSI11, SCK12, MISO13; no card during latest recorded probe | Card mount and file read/write |
| IR RX/TX | GPIO14/38 configured | Electrical and functional tests |
| Battery circuit | Disconnected during electrical checks; case contains mounting provisions | Specify and validate a regulated power path |
| Enclosure revision 2 | Parametric build checks solid validity, clearances, shell mating and wire volume | Physical print and fit test against exact module variants |

The no-card-detect configuration can print a card-detected message without a usable card. Treat successful mount and file read/write as the actual storage test.

The pin map does not promise simultaneous operation of all SPI features; firmware changes ownership of shared resources. The second/third NRF24 sockets are not fitted, and the second radio's placeholder pins conflict with IR.

The enclosure is 96.4 × 168.4 × 94.0 mm and is based on a YD-style DevKit/module dimension model. It includes estimated dimensions for some parts and a loose-wire packing allowance. A separate boost converter has no dedicated mount. Inspect the slicer and print the front plate first to check display/joystick fit.

The repository was republished with a fresh root commit under `esp32-rkstlohchab`. Required third-party license notices remain. Removing Git branch/tag history does not recall external clones or guarantee removal of GitHub's cached old commit URLs.

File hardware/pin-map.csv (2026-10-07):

module | module_pin | esp32_gpio | firmware_macro | notes | status | connection_route
Joystick | VRX | 4 | JOY_X_PIN | ADC1 | Verified | Dedicated signal: direct ESP32 jumper
Joystick | VRY | 5 | JOY_Y_PIN | ADC1 | Verified | Dedicated signal: direct ESP32 jumper
Joystick | SW | 6 | JOY_SW_PIN | Active-low; internal pull-up | Verified | Dedicated signal: direct ESP32 jumper
TFT ILI9341 | SDI / MOSI | 15 | TFT_MOSI_PIN | Display SPI | Verified | Shared breadboard signal row: GPIO15
TFT ILI9341 | SCK | 47 | TFT_SCLK_PIN | Display SPI | Verified | Shared breadboard signal row: GPIO47
TFT ILI9341 | SDO / MISO | 48 | TFT_MISO_PIN | Display SPI; onboard RGB disabled | Verified | Shared breadboard signal row: GPIO48
TFT ILI9341 | CS | 39 | TFT_CS_PIN | Display select | Verified | Dedicated signal: direct ESP32 jumper
TFT ILI9341 | DC | 9 | TFT_DC_PIN | Display data / command | Verified | Dedicated signal: direct ESP32 jumper
TFT ILI9341 | RESET | 8 | TFT_RST_PIN | Display reset | Verified | Dedicated signal: direct ESP32 jumper
Touch XPT2046 | T_DIN | 15 | XPT2046_MOSI | Shares TFT MOSI | Verified | Shared breadboard signal row: GPIO15
Touch XPT2046 | T_CLK | 47 | XPT2046_CLK | Shares TFT SCK | Verified | Shared breadboard signal row: GPIO47
Touch XPT2046 | T_DO | 48 | XPT2046_MISO | Shares TFT MISO | Verified | Shared breadboard signal row: GPIO48
Touch XPT2046 | T_CS | 45 | XPT2046_CS | Boot strapping pin; preserve reset levels | Verified | Dedicated signal: direct ESP32 jumper
Touch XPT2046 | T_IRQ | 46 | XPT2046_IRQ | Wired; touch is polled; boot strapping pin | Verified | Dedicated signal: direct ESP32 jumper
NRF24L01+ | CSN | 7 | CSN_PIN_1 | Radio SPI | SPI verified | Dedicated signal: direct ESP32 jumper
NRF24L01+ | CE | 16 | CE_PIN_1 | Radio enable | SPI verified | Dedicated signal: direct ESP32 jumper
NRF24L01+ | SCK | 17 | NRF24_SPI_SCK | Radio SPI | SPI verified | Dedicated signal: direct ESP32 jumper
NRF24L01+ | MOSI | 18 | NRF24_SPI_MOSI | Radio SPI | SPI verified | Dedicated signal: direct ESP32 jumper
NRF24L01+ | MISO | 21 | NRF24_SPI_MISO | Radio SPI | SPI verified | Dedicated signal: direct ESP32 jumper
MicroSD | CS | 10 | SD_CS | Storage SPI | Wired; card read/write pending | Dedicated signal: direct ESP32 jumper
MicroSD | MOSI / DI | 11 | SD_MOSI | Storage SPI | Wired; card read/write pending | Shared breadboard signal row: GPIO11
MicroSD | SCK / CLK | 12 | SD_SCLK | Storage SPI | Wired; card read/write pending | Shared breadboard signal row: GPIO12
MicroSD | MISO / DO | 13 | SD_MISO | Shared with CC1101 | Wired; card read/write pending | Shared breadboard signal row: GPIO13
CC1101 | CS | 40 | CC1101_CS | Storage SPI | SPI verified | Dedicated signal: direct ESP32 jumper
CC1101 | MOSI | 11 | CC1101_MOSI | Shared storage MOSI | SPI verified | Shared breadboard signal row: GPIO11
CC1101 | SCK | 12 | CC1101_SCK | Shared storage SCK | SPI verified | Shared breadboard signal row: GPIO12
CC1101 | MISO | 13 | CC1101_MISO | Shared storage MISO | SPI verified | Shared breadboard signal row: GPIO13
CC1101 | GDO0 | 1 | CC1101_GDO0 | Single asynchronous RX/TX data line | SPI verified; RF regression pending | Dedicated signal: direct ESP32 jumper
PN532 | SS / CS | 2 | PN532_SS | SPI mode: SW1 OFF / SW2 ON | Firmware query verified | Dedicated signal: direct ESP32 jumper
PN532 | MOSI | 11 | PN532_MOSI | Bit-banged; shares storage MOSI | Firmware query verified | Shared breadboard signal row: GPIO11
PN532 | SCK | 12 | PN532_SCK | Bit-banged; shares storage SCK | Firmware query verified | Shared breadboard signal row: GPIO12
PN532 | MISO | 42 | PN532_MISO | Dedicated return; not GPIO13 | Firmware query verified | Dedicated signal: direct ESP32 jumper
GPS NEO-6M | TX | 41 | GPS_UART_RX | 9600 baud; module RX unconnected | Valid NMEA verified | Dedicated signal: direct ESP32 jumper
IR receiver | OUT | 14 | IR_RX_PIN | Conflicts with unfitted NRF24 #2 CE | Electrical test pending | Dedicated signal: direct ESP32 jumper
IR transmitter | Signal | 38 | IR_TX_PIN | Conflicts with unfitted NRF24 #2 CSN | Electrical test pending | Dedicated signal: direct ESP32 jumper

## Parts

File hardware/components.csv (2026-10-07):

item | component | quantity | specification | status
1 | ESP32-S3 N16R8 DevKit | 1 | 16 MB flash; 8 MB OPI PSRAM; YD board assumed by enclosure | USB-powered build verified
2 | TPM408-2.8 TFT + XPT2046 | 1 | 2.8 inch ILI9341 display with resistive touch | Display and calibrated touch verified
3 | KY-023 joystick | 1 | Power potentiometers from 3V3 | Verified
4 | NRF24L01+ PA/LNA + antenna | 1 | 3V3 only; 10–47 uF local decoupling | SPI verified
5 | CC1101 E07-M1101D-SMA + antenna | 1 | 3V3; GDO0 shared for asynchronous RX/TX | SPI verified; RF functions require testing
6 | PN532 NFC V3 | 1 | SPI; SW1 OFF / SW2 ON for the tested module | Firmware version query verified; card tests pending
7 | Separate SPI microSD reader + card | 1 | FAT32/FAT16 card; VCC depends on regulator/level shifting | Wired; card read/write pending
8 | NEO-6M GY-GPS6MV2 + ceramic antenna | 1 | GPS TX to GPIO41; common GND; verify breakout supply rating | Valid NMEA stream verified; outdoor fix not established here
9 | KY-005 IR transmitter | 1 | Signal GPIO38; check module driver/current requirements | Assigned; electrical test pending
10 | KY-022 IR receiver | 1 | Output GPIO14; use ESP32-safe 3.3 V signal levels | Assigned; electrical test pending
11 | 400-point breadboard | 1 | 83.5 x 54.5 x 8.5 mm assumed in enclosure | Power distribution and wiring
12 | Dupont jumper wires | 60 x 20 cm + 5 x 40 cm | Enclosure packing assumption; up to 2 mm insulation diameter | Check actual wiring length and connectors
13 | 10–47 uF capacitor | 1 | Across NRF24 VCC/GND close to radio; observe polarity | Radio supply decoupling
14 | USB data cable + supply | 1 | Use board native USB for firmware serial | Current verified power arrangement
15 | 18650 cell + holder | 1 | Holder pocket 78.9 x 21.9 mm; cell nominal length 65 mm | Mechanical provision; disconnected in electrical tests
16 | TP4056 USB-C charger | 1 | Mechanical provision; not a complete regulated battery power path | Battery circuit unverified/disconnected
17 | SS12D00 power switch | 1 | Mechanical provision | Battery circuit unverified/disconnected
18 | Lid / display / joystick fasteners | 4 x M2.5x8; 4 x M3x6; 2 x M3x8 | Countersunk lid screws; removable tape/foam for unmounted modules | Check fasteners against printed parts

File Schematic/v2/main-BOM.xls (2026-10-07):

Comment | Description | Designator | Footprint | LibRef | Quantity
CONN-TH |  |  | PCBComponent_1 | CONN-TH | 1
Tactle Switch |  | *1, *2, *3, *4, *5 | PCBComponent_1 | Tactle Switch | 5
ANT U.FL | Antenna | ANT1 | U.FL SMD | ANT U.FL | 1
BUTTON | PUSH BUTTON | BOOT, ON/OFF1, RESET | PUSH BUTTON SMD | PUSH BUTTON RIGHT | 3
Battery |  | BT1 | Bat | Battery | 1
100nf | Capacitor | C1, C14, C16, C17, C18 | C 0805 | CAP SMD | 5
Capacitor Tantalum SMD | Capacitor Tantalum SMD | C2, C3 | Tan 1206 (3216X18L) Size A | Capacitor Tantalum SMD | 2
10uf | Capacitor | C4, C5 | CAP 1206 (3216X15L) | CAP SMD | 2
10uf | Capacitor | C6, C7, C8, C9, C13, C15 | C 0805 | CAP SMD | 6
22uf | Capacitor | C10, C11, C12 | C 0805 | CAP SMD | 3
WS2812B2020 | LED; SMD; 2020; RGB; 2x2x0.84mm; 3.7Ã·5.3V; Lens: transparent; 2kHz | D1, D2, D3, D4 | LED_WS2812B2020 | WS2812B2020 | 4
TYPE-C-31-M-12 | USB Connectors 24 Receptacle 1 8.94*7.3mm RoHS | J1, J2 | HRO_TYPE-C-31-M-12 | TYPE-C-31-M-12 | 2
TSM-110-04-S-DV | Conn Unshrouded Header HDR 20 POS 2.54mm Solder ST SMD Tube | J3 | SAMTEC_TSM-110-04-S-DV | TSM-110-04-S-DV | 1
SMA | SMA Connector Jack, Female Socket 50Ohm Board Edge, End Launch Solder | J4 | SAMTEC_SMA-J-P-H-ST-EM1 | SMA-J-P-H-ST-EM1 | 1
Inductor SMD Cored |  | L1 | L_57 | Inductor SMD Cored | 1
CMT-7525-80-SMT-TR | 7.5 mm, 3.6 Vo-p, 80 dB, Surface Mount (SMT), Magnetic Audio Transducer Buzzer | LS1 | XDCR_CMT-7525-80-SMT-TR | CMT-7525-80-SMT-TR | 1
S8050 | Bipolar (BJT) Transistor NPN 25 V 500 mA 150MHz 300 mW Surface Mount SOT-23 | Q1, Q2, Q3 | SOT-23 | SMD-TRANSISTORS-NPN-25V-500MW(SOT-23) | 3
SI2302 | N-Channel 20 V 2.6A (Ta) 710mW (Ta) Surface Mount SOT-23-3 (TO-236) | Q4 | SOT23 | SI2302 | 1
10k | RESISTOR | R1, R2, R3, R4, R7, R15, R35 | RES 0805 (2012X06L) | RES | 7
1k | RESISTOR | R5, R6, R9, R12, R13, R14, R17, R18, R28, R29, R30, R31, R32, R33 | RES 0805 (2012X06L) | RES | 14
100k | RESISTOR | R8, R11, R16 | RES 0805 (2012X06L) | RES | 3
0.5R | RESISTOR | R10 | RES 0805 (2012X06L) | RES | 1
4.7k | RESISTOR | R19, R21 | RES 0805 (2012X06L) | RES | 2
470 | RESISTOR | R20 | RES 0805 (2012X06L) | RES | 1
5.1k | RESISTOR | R22, R23, R26, R27 | RES 0805 (2012X06L) | RES | 4
12k | RESISTOR | R24, R25 | RES 0805 (2012X06L) | RES | 2
10R | RESISTOR | R34 | RES 0805 (2012X06L) | RES | 1
LED | LED | RX, TX | LED_0603 | LED | 2
1n4007 | Diode 1n4007 | SS1 | Diode 1N4007 SMD | Diode 1n4007 | 1
SlideSwitch | SWITCH, SLIDE, SPDT, SMD | SW1 | SWSLIDT_SPDT_MSS3 | SWSLIDT_SPDT_MSS3 | 1
SD CARD SPI MODE | SD CARD SPI MODE | U1 | MICRO SD | SD CARD SPI MODE | 1
LF33 | 3.3V VOLTAGE REGULATOR | U2 | D-PACK | LF33 | 1
AO3401 | P-Channel 30 V 4A (Ta) 1.4W (Ta) Surface Mount SOT-23-3 | U3 | SOT23-3 | AO3401 | 1
IP5306 | IC Power Bank, 2.1A charger, 2.4A discharger | U4 | SO_8T | IP5306_SO8T | 1
ESP32-S3-WROOM-1U-N16 | Bluetooth, WiFi 802.11b/g/n, Bluetooth v5.0 Transceiver Module 2.4GHz Antenna Not Included, U.FL Surface Mount | U5 | XCVR_ESP32-S3-WROOM-1U-N16 | ESP32-S3-WROOM-1U-N16 | 1
CP2102 | USB Bridge, USB to UART USB 2.0 UART Interface 28-QFN _5x5_ | U6 | QFN28G_0.5-5X5MM | INTERFACE-CP2102-GMR(QFN28) | 1
XPT2046 | Touch Screen Controller | U7 | TSSOP16 | XPT2046 | 1
2.8 240X320_ILI9341 | LCD TFT FULL Color 2.8 240X320 ILI9341 Driver FLAT | U8 | LCDTFT_1.8IN_ST7735_18P | LCD_TFT_Color_2.8 240X320_ILI9341 Driver_FLAT | 1
PCF8574T | I/O Expander 8 IÂ²C 100 kHz 20-SSOP | U9 | SOIC127P1032X265-16N | PCF8574T | 1

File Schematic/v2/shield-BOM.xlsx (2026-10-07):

Comment | Description | Designator | Footprint | LibRef | Quantity
ANT U.FL | Antenna | ANT1, ANT2, ANT3, ANT4, ANT5, ANT6, ANT7, ANT8 | U.FL SMD | ANT U.FL | 8
Capacitor Tantalum SMD | Capacitor Tantalum SMD | C1, C2, C3 | Tan 1206 (3216X18L) Size A | Capacitor Tantalum SMD | 3
LED IR-S | LED | D2 | LED 3mm | LED IR-S | 1
TSM-110-04-S-DV | Conn Unshrouded Header HDR 20 POS 2.54mm Solder ST SMD Tube | J1 | SAMTEC_TSM-110-04-S-DV | TSM-110-04-S-DV | 1
SMA | SMA Connector Jack, Female Socket 50Ohm Board Edge, End Launch Solder | J2, J3, J4, J5, J6, J7, J8, J9, J10, J11 | SAMTEC_SMA-J-P-H-ST-EM1 | SMA-J-P-H-ST-EM1 | 10
TSOP1838 | IR Remote Receiver 38KHz 35m 3-Pin | J12 | TSOP1838 | TSOP1838 | 1
Header 10X2 | Header, 10-Pin, Dual row | P1 | HDR2X10 | Header 10X2 | 1
SMD | Bipolar (BJT) Transistor NPN 25 V 500 mA 150MHz 300 mW Surface Mount SOT-23 | Q1 | SOT-23 | SMD-TRANSISTORS-NPN-25V-500MW(SOT-23) | 1
1k | RESISTOR | R1 | RES 0805 | RES | 1
0R | RESISTOR | R2, R3, R4, R5 | RES 0805 | RES | 4
LED | LED | Rx1 | L0805 | LED | 1
NRF24L01 | 2.4GHz Transceiver MODULE, SMD | U1, U2, U3 | NRF24L01_GT24MINI_MS | NRF24L01_GT24MINI_MS | 3
CC1101 | RF 433MHz, 10mW | U4 | CC1101_SMD | CC1101_M_SMD | 1

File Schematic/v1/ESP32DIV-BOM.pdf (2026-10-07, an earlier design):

Comment | Description | Designator | Footprint | LibRef | Quantity
ANT U.FL | Antenna | ANT1, ANT2, ANT3, ANT4 | U.FL SMD | ANT U.FL | 4
Button | PUSH BUTTON | B1, B2, B3, B4, B5, B6 PUSH BUTTON 4 PIN | SMD 5 | PUSH BUTTON 4 PIN | 6
Button | TACTILE SWITCH | B7 | PUSH BUTTON 12*12*8.5mm | TACTILE SWITCH | 1
BUTTON | PUSH BUTTON | BOOT1, RESET1 | PUSH BUTTON SMD | PUSH BUTTON RIGHT | 2
1042 | | BT1 | BAT_1042 | 1042 | 1
Battery | | BT2 | Bat | Battery | 1
100nf | Capacitor | C1, C3, C5, C6, C7, C8, C13 | CAP0805 | CAP SMD | 7
10uf | Capacitor | C2, C4 | CAP0805 | CAP SMD | 2
Capacitor Tantalum SMD | Capacitor Tantalum SMD | C9, C10 | Tan 1206 (3216X18L) Size A | Capacitor Tantalum SMD | 2
10uf | Capacitor | C11, C12 | CAP 1206 (3216X15L) | CAP SMD | 2
LED | LED | CHG1, Rx1, STD1, Tx1 | L0805 | LED | 4
TP4056 | Complete single cell Li-Ion battery with a constant current / constant voltage linear charger | IC1 | SOP-8 | TP4056 | 1
TYPE-C-31-M-12 | USB Connectors 24 Receptacle 1 8.94*7.3mm RoHS | J1 | HRO_TYPE-C-31-M-12 | TYPE-C-31-M-12 | 1
SMA | SMA Connector Jack, Female Socket 50Ohm Board Edge, End Launch Solder | J2, J3, J4, J5 | SAMTEC_SMA-J-P-H-ST-EM1 | SMA-J-P-H-ST-EM1 | 4
N-Header 10X2 | | P1 | N-Header 10X2 | N-Header 10X2 | 1
S8050 | Bipolar (BJT) Transistor NPN 25 V 500 mA 150MHz 300 mW Surface Mount SOT-23 | Q1, Q2, Q3 | SOT-23 | SMD-TRANSISTORS-NPN-25V-500MW(SOT-23) | 3
4.7k | RESISTOR | R1, R3 | RES 0805 | RES | 2
470 | RESISTOR | R2 | RES 0805 | RES | 1
12k | RESISTOR | R4, R9 | RES 0805 | RES | 2
10K | RESISTOR | R5, R6, R7, R8 | RES 0805 | RES | 4
1k | RESISTOR | R10, R11, R14, R15, R16, R17, R18, R19, R20, R21, R22, R23, R26 | RES 0805 | RES | 13
5.1k | RESISTOR | R12, R13 | RES 0805 | RES | 2
10R | RESISTOR | R24, R25 | RES 0805 | RES | 2
SlideSwitch | SWITCH, SLIDE, SPDT, SMD | SW1 | SWSLIDT_SPDT_MS S3 | SWSLIDT_SPDT_MS S3 | 1
SD CARD SPI MODE | SD CARD SPI MODE | U1 | MICRO SD | SD CARD SPI MODE | 1
ESP32-WROOM-32U | Bluetooth, WiFi 802.11b/g/n, Bluetooth v4.2 +EDR, Class 1, 2 and 3 Transceiver Module 2.4GHz ~ 2.5GHz Antenna Not Included, U.FL Surface Mount | U2 | XCVR_ESP32-WROOM-32U | ESP32-WROOM-32U | 1
CP2102 | USB Bridge, USB to UART USB 2.0 UART Interface 28-QFN _5x5_ | U3 | QFN28G_0.5-5X5MM | INTERFACE-CP2102-GMR(QFN28) | 1
LF33 | 3.3V VOLTAGE REGULATOR | U4 | D-PACK | LF33 | 1
PCF8574T | I/O Expander 8 IÂ²C 100 kHz 20-SSOP | U5 | SOIC127P1032X265-16N | PCF8574T | 1
2.8 240X320_ILI9341 | LCD TFT FULL Color 2.8 240X320 ILI9341 Driver FLAT | U6 | LCDTFT_1.8IN_ST77 35_18P | LCD_TFT_Color_2.8 240X320_ILI9341 Driver_FLAT | 1
XPT2046 | Touch Screen Controller | U7 | TSSOP16 | XPT2046 | 1

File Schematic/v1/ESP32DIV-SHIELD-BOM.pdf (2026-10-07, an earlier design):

Comment | Description | Designator | Footprint | LibRef | Quantity
ANT U.FL | Antenna | ANT1 | U.FL SMD | ANT U.FL | 1
100uF50V | Cap electrolitic radial | C1, C2, C3 | Cap electrolitic radial 5x11-2 | Cap ELECTROLITIC TOTAL SIZE | 3
LED IR-R | LED | D1 | LED 3mm BLACK | LED IR-R | 1
LED IR-S | LED | D2 | LED 3mm | LED IR-S | 1
SMA | SMA Connector Jack, Female Socket 50Ohm Board Edge, End Launch Solder | J1, J2 | SAMTEC_SMA-J-P-H-ST-EM1 | SMA-J-P-H-ST-EM1 | 2
M-Header 10X2 | | P1 | M-Header 10X2 | M-Header 10X2 | 1
N-Header 10X2 | | P2 | N-Header 10X2 | N-Header 10X2 | 1
Header 2X2 | Header, 2-Pin, Dual row | P3 | HDR2X2 | Header 2X2 | 1
1k | RESISTOR | R1, R2 | RES 0805 | RES | 2
0R | RESISTOR | R3 | RES 0805 | RES | 1
LED | LED | Rx1, Rx2 | L0805 | LED | 2
CC1101 | RF 433MHz, 10mW | U1 | CC1101_SMD | CC1101_M_SMD | 1
NRF24L01 | 2.4GHz Transceiver MODULE, SMD | U2, U3, U4 | NRF24L01_GT24MINI _MS | NRF24L01_GT24MINI _MS | 3

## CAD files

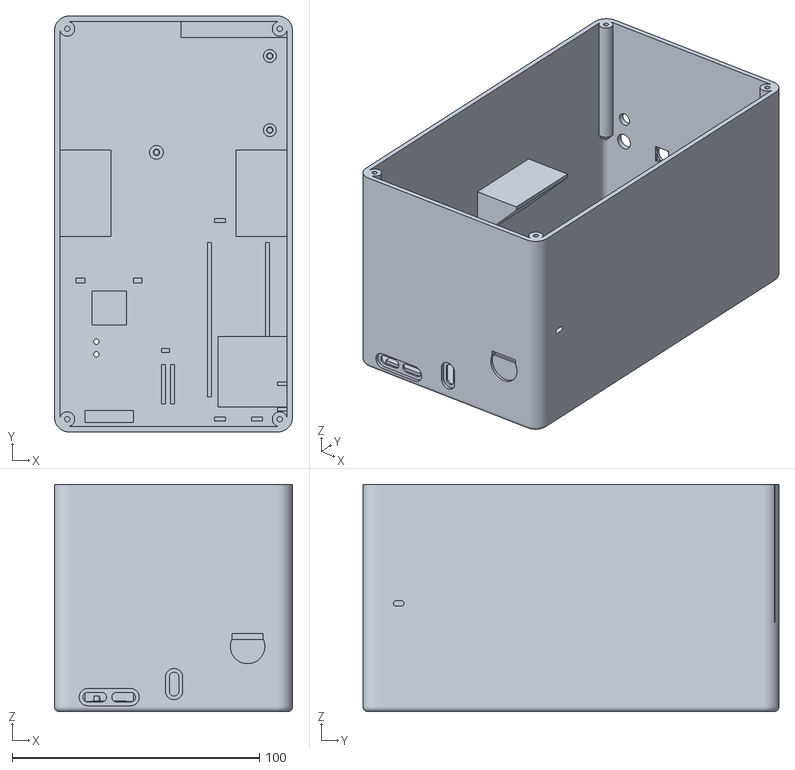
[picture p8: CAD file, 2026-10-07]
enclosure/stl/enclosure_back_tub.stl
96.4 x 168.4 x 92.0

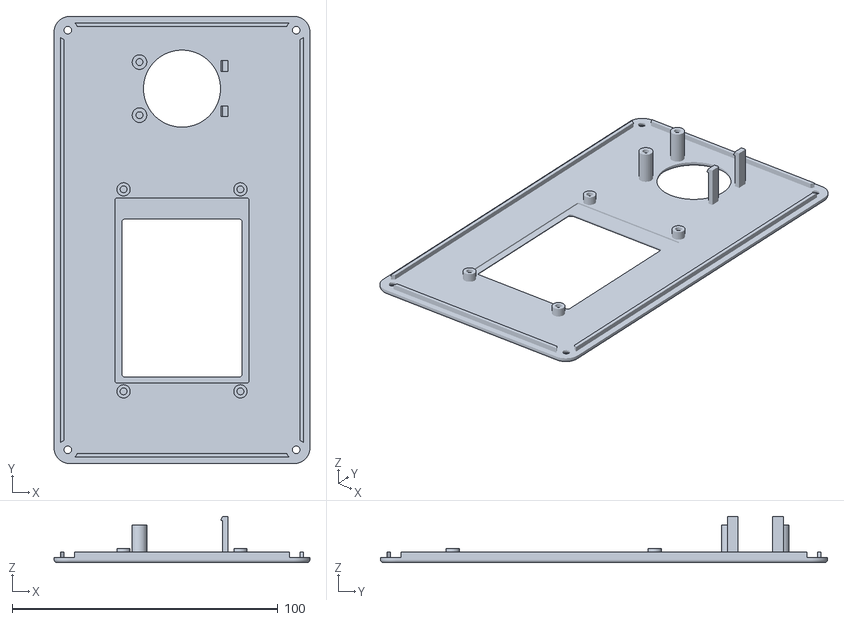
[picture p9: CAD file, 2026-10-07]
enclosure/stl/enclosure_front_plate.stl
96.4 x 168.4 x 17.5

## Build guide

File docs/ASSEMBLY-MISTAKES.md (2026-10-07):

# Assembly mistakes and fixes from this build

These are recorded project problems, not a list of hypothetical faults. Current wiring is in the [connection diagram](../hardware/wiring.svg), [breadboard guide](../hardware/BREADBOARD.md), and [pin map](../hardware/pin-map.csv). A successful compile does not prove a module works electrically.

## PN532 NFC: the tiny mode switches were set incorrectly

The PN532 board has **two small mode switches**, often referred to as buttons. They select the communication interface; they are not scan/start buttons. Our firmware uses the four-argument Adafruit PN532 **software SPI** constructor.

We originally left **SW1 OFF / SW2 OFF**, which selected UART on the tested V3 module. SPI probes consequently failed even though the firmware was configured for SPI. After setting **SW1 OFF / SW2 ON**, the firmware query returned **0x32010607**, identifying PN532 firmware 1.6, on two boots (2026-10-05).

Power down before changing the mode. On our board, switch 1 is away from the printed `ON` side, and switch 2 is toward `ON`. Read the switch numbers and `ON` marking rather than relying on “up/down”: board orientation changes those directions. Check the mode table printed on your exact module if it differs.

Our final SPI connections are **SS/CS → GPIO2, MOSI → GPIO11, SCK → GPIO12, MISO → GPIO42**, plus the documented supply and common GND. SDA/SCL are not used for this SPI setup. An earlier firmware CS assignment did not match GPIO2 and was corrected. The PN532 MISO is dedicated GPIO42, not the SD/CC1101 MISO13 net. A version response confirms SPI communication; NFC tag reading/writing remains a separate test.

## GPS: missing common ground

The GPS stream became valid after its GND was connected to the shared ground bus. GPS TX alone was insufficient. The corrected wiring is **GPS TX → ESP32 GPIO41**, GPS GND → common GND, with the module supplied at its breakout's rated voltage. GPS RX stays open; the firmware's GPIO0 TX placeholder is not a wire to add.

After the ground fix, the diagnostic received **7,799 bytes and 282 valid NMEA lines in 47 seconds at 9600 baud**. Valid NMEA traffic is not the same as an outdoor satellite fix.

## Display: incompatible pin assignments and panel configuration

Earlier maps placed display pins on GPIO33–37, which are occupied by the N16R8 module's octal PSRAM. The display was moved to its current wiring. TFT CS was also moved off **GPIO20**, which belongs to native USB, to **GPIO39**.

The TPM408-2.8 panel needs our TFT_eSPI setup and rotation patch. Without them, the observed image was rotated by 90 degrees, had roughly 80 noisy rows, and showed swapped red/blue colors. Apply both files in [tft_espi-patch](../tft_espi-patch/README.md). Current TFT signals are MOSI15, SCK47, MISO48, CS39, DC9, RESET8; touch shares the three data/clock nets with CS45 and IRQ46.

The onboard RGB LED is disabled because GPIO48 is now display MISO. Backlight is hardwired to 3V3; GPIO42 is PN532 MISO and must not be driven as backlight PWM.

## Alternate UI: title showed but the menu did not

The embedded board profile enabled the screen but omitted full-screen menu rendering. It also enabled an incompatible RGB configuration on joystick GPIO4/5/6 and used PN532 GPIO42 for backlight.

The fix enabled menu rendering, removed those conflicting outputs, initialized calibrated DIV input, and required release of the joystick's boot click before menu navigation. Later row-only redraws fixed full-screen blinking. The user confirmed that the menu appeared, the joystick worked, and the screen was steady. See the retained [UI fix notes](../MARAUDER-UI-FIX.md).

## SD card: “detected” did not prove a working card

Our reader has no card-detect switch. The configured no-detect path can assume presence and print a detected message even without a usable card. There was no card inserted during the latest recorded diagnostic. Treat **successful mount plus create/read/delete** as the storage test, not the detected banner. Use FAT32/FAT16 and all four SPI signals, including MISO13.

The recorded evidence does **not** establish that we omitted MISO on this build; that is a wiring check, not a confirmed past mistake.

## Firmware deauther: one byte beyond the frame

The existing Div implementation wrote index 26 of a 26-byte buffer. The valid indices are 0–25. We corrected the reason bytes to indices 24 and 25 and retained the existing implementation. A host frame test passed address and undefined-behavior sanitizers; no radio test was performed for that fix.

## Old notes: conflicting pin maps

Early circuit notes described PN532 I2C, different display pins, and older enclosure dimensions. They are historical, not the final breadboard schematic. Current documents are generated/checked against `ESP32-DIV/BoardConfig.h`. On the breadboard, keep each shared net isolated: GPIO11, 12, 13, 15, 47 and 48 each get a separate connected strip. Do not merge unrelated pins just because they have the same SPI signal name.

## Evidence sources

The PN532/GPS results and final rewiring are recorded in [PORT.md](../PORT.md). UI fixes and user confirmations are recorded in [MARAUDER-UI-FIX.md](../MARAUDER-UI-FIX.md). The display behavior is recorded in the [TFT patch notes](../tft_espi-patch/README.md). Current test limits are summarized in [STATUS.md](STATUS.md).

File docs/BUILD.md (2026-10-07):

# Build and flash

Target: **ESP32-S3 N16R8** (16 MB flash, 8 MB OPI PSRAM), TPM408-2.8 ILI9341 + XPT2046, KY-023 joystick.

## Quick firmware download

Use the current files in [`firmware/`](../firmware/README.md). They were compiled from this repository's branded firmware snapshot. The old upstream web flasher and bundled board binaries are not the current N16R8 build.

## Build prerequisites

Install Arduino IDE / Arduino CLI and the **Espressif ESP32 core 2.0.10**. Core 3.x is not validated for this code. Open [`ESP32-DIV/ESP32-DIV.ino`](../ESP32-DIV/ESP32-DIV.ino).

Known versions used on the build machine:

| Library | Version |
|---|---|
| NimBLE-Arduino | 1.4.3 |
| ArduinoJson | 6.21.5 |
| arduinoFFT | 1.6.2 |
| TFT_eSPI | 2.5.43, with the required patch below |
| SmartRC-CC1101-Driver-Lib | 2.5.7, with the local fixes below |

Other sketch dependencies: Adafruit PN532, Adafruit BusIO, RF24, IRremoteESP8266, rc-switch, XPT2046_Touchscreen, ESP32Ping, EspSoftwareSerial, MicroNMEA, LinkedList, AsyncTCP, and the PCF8574 library for profiles that use it. Install these in your Arduino sketchbook libraries directory. This dependency set was used on the local build machine; a fresh-machine dependency installation has not been exercised by this documentation update.

### Required local library configuration

1. Apply both files from [`tft_espi-patch/`](../tft_espi-patch/README.md) to TFT_eSPI 2.5.43: `User_Setup.h` and `TFT_Drivers/ILI9341_Rotation.h`. They configure GPIO15/47/48, CS39, DC9, RESET8, touch CS45 and the TPM408 panel's axis-swapped rotation/RGB order.
2. In SmartRC-CC1101-Driver-Lib 2.5.7, avoid compiling duplicate `ELECHOUSE_CC1101_SRC_JT_DRV.*` implementations. The tested library has these stored under `jamtool_unused/`. Its `ELECHOUSE_CC1101_SRC_DRV.cpp` also declares the file-local flag as `static bool spi = 0;` to avoid collision with TFT_eSPI.
3. The tested ESP32 core uses a `platform.local.txt` overlay that prepends `-zmuldefs` to its existing `compiler.c.elf.libs.*` values. This permits the sketch's SDK symbol overrides and the merged implementations to link. Preserve the core's existing link libraries when applying it; do not replace the list with just that flag. [`Libraries/platform.txt`](../Libraries/platform.txt) is an upstream reference, not a replacement for arbitrary core versions.

These are external library/core edits; cloning this repository alone does not apply them. Reapply the display patch after library updates. `BoardConfig.h` and the TFT_eSPI configuration must agree.

## Board settings

| Setting | Value |
|---|---|
| Board | ESP32S3 Dev Module |
| USB CDC On Boot | Enabled |
| USB Mode | Hardware CDC and JTAG |
| CPU | 240 MHz |
| Flash mode | QIO, 80 MHz |
| Flash size | 16 MB |
| PSRAM | OPI PSRAM |
| Partition scheme | 16M Flash (3MB APP/9.9MB FATFS) |

```sh
arduino-cli compile \
  --fqbn 'esp32:esp32:esp32s3:PSRAM=opi,FlashSize=16M,PartitionScheme=app3M_fat9M_16MB,CDCOnBoot=cdc,FlashMode=qio,CPUFreq=240,USBMode=hwcdc' \
  --output-dir build/firmware ESP32-DIV
```

Latest checked result (2026-10-08): application **2,724,621 bytes / 3,145,728**; static RAM **159,604 bytes / 327,680**. The selected partition layout has two 3 MB app slots, but this is not evidence of a working wireless OTA flow.

## Flash precompiled binaries

Verify `firmware/SHA256SUMS.txt` first. Install esptool compatible with the following v4 command syntax. From the repository root, replace `YOUR_SERIAL_PORT` with the connected ESP32's port:

```sh
python3 -m esptool --chip esp32s3 --port YOUR_SERIAL_PORT --baud 460800 \
  write_flash --flash_mode qio --flash_freq 80m --flash_size 16MB \
  0x0000 firmware/ESP32-DIV.ino.bootloader.bin \
  0x8000 firmware/ESP32-DIV.ino.partitions.bin \
  0xe000 firmware/boot_app0.bin \
  0x10000 firmware/ESP32-DIV.ino.bin
```

This writes the bootloader, partition table, OTA selection data and application. It can replace firmware and change the partition layout; back up any device data you need first. The application `.bin` alone is not a complete first-flash package.

Alternatively, build in Arduino IDE with the settings above and use Upload. If manual BOOT/RESET was needed to enter download mode, press RESET after flashing. Open Serial Monitor at 115200 baud.

## Boot and bring-up

- Normal reset: primary UI.
- Hold joystick click during reset, then release: alternate full-screen UI.
- Joystick up/down selects; click/right opens; left returns. Restart to switch modes.
- Calibrate touch in the primary UI for your own panel; stored calibration can differ between panels.
- Mount a FAT32/FAT16 microSD card and test create/read/delete before relying on saved data.

See the [hardware guide](../hardware/README.md) and [verification record](STATUS.md) for the distinction between a wired module and a tested feature.

Before diagnosing a module, read the [recorded assembly mistakes](ASSEMBLY-MISTAKES.md). In particular, the tested PN532 requires SW1 OFF / SW2 ON for SPI.

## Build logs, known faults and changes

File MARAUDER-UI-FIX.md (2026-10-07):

# Marauder joystick boot / blank menu fix

The MULTIBOARD_S3 profile enabled HAS_SCREEN but omitted HAS_FULL_SCREEN.
The title rendered while the menu row renderer was compiled out. Its Flipper
RGB configuration also claimed joystick GPIO4/5/6, and backlight claimed
PN532 GPIO42.

Changes: enable menu rendering; disable the incompatible LED output;
initialize DIV joystick/calibrated touch; debounce input and require release
of the boot click; keep other SPI slaves deselected; use SD FSPI12/13/11 CS10;
suppress PWM for the hardwired backlight.

Verification: Arduino CLI build passed for ESP32-S3 N16R8 (87% application
partition, 48% static RAM). Flashed via /dev/cu.usbmodem101 with esptool hash
verification. User tested joystick-held boot and confirmed: **“Menu appears
and joystick works.”** Normal DIV boot reached `[boot] ready`. A subsequent
brightness guard removes calls to unattached PWM; menu behavior is unchanged.
No radio attack or full module regression tests were performed for this fix.

Boot normally for DIV. Hold joystick click while resetting for Marauder,
then release. Up/down moves selection, click/right opens, left goes back.
Restart to switch modes.

Follow-up: joystick navigation now redraws only the old/new selection rows.
Scrolling onto another page repaints its rows without clearing the TFT or
redrawing the banner/status bar. Persistently selected items retain their
highlight. This addresses the full-screen blink reported after the first fix.
Compiled and flashed with hash verification. A host harness exercising the
actual navigation block passed row-only redraw, wraparound, pagination,
persistent selections, settings rows, click and root Back checks.
User then confirmed the flashed follow-up: **“Yes, the screen is steady.”**

Status legend: CH is Wi-Fi channel; D is internal DRAM usage; a red SD icon
means no card is mounted. The side tick marks divide up/select/down touch zones.

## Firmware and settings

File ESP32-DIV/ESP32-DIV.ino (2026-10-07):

#include <Arduino.h>
#include "src/marauder/marauder_app.h"   // MERGE: embedded Marauder UI + serial CLI
#if !(defined(USE_JOYSTICK_NAV) && USE_JOYSTICK_NAV)
#include <PCF8574.h>   /* PORT: only needed for the real I2C port expander */
#endif
#include <TFT_eSPI.h>
#include <Wire.h>
#include "SettingsStore.h"
#include "Touchscreen.h"
#include "config.h"
#include "ducky.h"
#include "icon.h"
#include "ir.h"
#include "gps.h"
#include "rfid.h"
#include "shared.h"
#include "utils.h"

#if !BOARD_HAS_ESP32S3
#include "soc/soc.h"
#include "soc/rtc_cntl_reg.h"
#endif

TFT_eSPI tft = TFT_eSPI();

NavExpander pcf(PCF8574_I2C_ADDR);

void setBrightness(uint8_t value) {
#if BACKLIGHT_PIN >= 0
  ledcWrite(PWM_CHANNEL, value);
#else
  (void)value; // Hardwired backlight: no PWM channel is attached.
#endif
}

bool feature_exit_requested = false;

const int NUM_MENU_ITEMS = 8;
const char *menu_items[NUM_MENU_ITEMS] = {
    "WiFi",
    "2.4GHz",
    "More",
    "Settings",
    "Bluetooth",
    "SubGHz",
    "Tools",
    "About"};

const unsigned char *bitmap_icons[NUM_MENU_ITEMS] = {
    bitmap_icon_wifi,
    bitmap_icon_jammer,
    bitmap_icon_dialog,
    bitmap_icon_setting,
    bitmap_icon_spoofer,
    bitmap_icon_analyzer,
    bitmap_icon_stat,
    bitmap_icon_question};

int current_menu_index = 0;
bool is_main_menu = false;

const int NUM_SUBMENU_ITEMS = 12;
const char *submenu_items[NUM_SUBMENU_ITEMS] = {
    "Packet Monitor",
    "Beacon Spammer",
    "WiFi Deauther",
    "Probe Request Flood",
    "Deauth Detector",
    "WiFi Scanner",
    "Captive Portal",
    "Hidden SSID Revealer",
    "WPS Scanner",
    "ARP Scanner",
    "Karma Attack",
    "Back to Main Menu"};

// WiFi submenu is split across two pages (features after Hidden SSID on page 2).
// Bottom row: icon | Main Menu                 Next/Prev Page | icon
static constexpr int WIFI_PAGE0_FEATURES = 8;
static constexpr int WIFI_PAGE1_FEATURES = 3;
static int wifi_submenu_page = 0;

const char *wifi_page0_items[WIFI_PAGE0_FEATURES] = {
    "Packet Monitor",
    "Beacon Spammer",
    "WiFi Deauther",
    "Probe Request Flood",
    "Deauth Detector",
    "WiFi Scanner",
    "Captive Portal",
    "Hidden SSID Revealer"};

const char *wifi_page1_items[WIFI_PAGE1_FEATURES] = {
    "WPS Scanner",
    "ARP Scanner",
    "Karma Attack"};

// Bluetooth submenu uses the same paged footer layout as WiFi.
static constexpr int BT_PAGE0_FEATURES = 8;
static constexpr int BT_PAGE1_FEATURES = 1;
static int bluetooth_submenu_page = 0;

const char *bluetooth_page0_items[BT_PAGE0_FEATURES] = {
    "BLE Jammer",
    "BLE Spoofer",
    "Sour Apple",
    "AirTag Spoofer",
    "AirTag Sniffer",
    "Sniffer",
    "BLE Scanner",
    "BLE Rubber Ducky"};

const char *bluetooth_page1_items[BT_PAGE1_FEATURES] = {
    "Skimmer Detect"};

static FeatureUI::Button s_pagedFooterBtns[2];
static int s_pagedFooterFocus = -1;  // 0=back, 1=page btn, -1=none

const int nrf_NUM_SUBMENU_ITEMS = 7;
const char *nrf_submenu_items[nrf_NUM_SUBMENU_ITEMS] = {
    "Scanner",
    "Proto Kill",
    "ESB Sniffer",
    "ESB Replay",
    "MouseJack Scan",
    "MouseJack Inject",
    "Back to Main Menu"};

const int subghz_NUM_SUBMENU_ITEMS = 6;
const char *subghz_submenu_items[subghz_NUM_SUBMENU_ITEMS] = {
    "Replay Attack",
    "SubGHz Jammer",
    "De Bruijn / Brute",
    "Jamming Detector",
    "Saved Profile",
    "Back to Main Menu"};

const int tools_NUM_SUBMENU_ITEMS = 5;
const char *tools_submenu_items[tools_NUM_SUBMENU_ITEMS] = {
    "Serial Monitor",
    "Update Firmware",
    "Touch Calibrate",
    "SD File Manager",
    "Back to Main Menu"};

static constexpr uint8_t OTHER_LAYER_HOME = 0;
static constexpr uint8_t OTHER_LAYER_IR   = 1;
static constexpr uint8_t OTHER_LAYER_RFID = 2;
static constexpr uint8_t OTHER_LAYER_GPS  = 3;

const int other_NUM_SUBMENU_ITEMS = 4;
static constexpr int OTHER_GRID_COLS = 2;
const char *other_submenu_items[other_NUM_SUBMENU_ITEMS] = {
    "IR Remote",
    "RFID/NFC",
    "GPS",
    "Main Menu"};

const int rfid_NUM_SUBMENU_ITEMS = 9;
const char *rfid_submenu_items[rfid_NUM_SUBMENU_ITEMS] = {
    "Card Reader",
    "Card Clone",
    "Erase",
    "Dump",
    "Decode Access",
    "Jam Reader",
    "Tag Disrupt",
    "Disrupt Emulate",
    "Back to Main Menu"};

const int gps_NUM_SUBMENU_ITEMS = 3;
const char *gps_submenu_items[gps_NUM_SUBMENU_ITEMS] = {
    "Wardriver",
    "Satellite Scanner",
    "Back to Main Menu"};

const int ir_NUM_SUBMENU_ITEMS = 4;
const char *ir_submenu_items[ir_NUM_SUBMENU_ITEMS] = {
    "Record",
    "Saved Profile",
    "Universal Controller",
    "Back to Main Menu"};

const int about_NUM_SUBMENU_ITEMS = 1;
const char *about_submenu_items[about_NUM_SUBMENU_ITEMS] = {
    "Back to Main Menu"};

const int setting_NUM_SUBMENU_ITEMS = 1;
const char *setting_submenu_items[setting_NUM_SUBMENU_ITEMS] = {
    "Back to Main Menu"};

int current_submenu_index = 0;
bool in_sub_menu = false;
int last_submenu_index = -1;
bool submenu_initialized = false;
uint8_t other_layer = OTHER_LAYER_HOME;
int last_other_menu_index = -1;
bool other_menu_grid_initialized = false;

const char **active_submenu_items = nullptr;
int active_submenu_size = 0;

const unsigned char *wifi_submenu_icons[NUM_SUBMENU_ITEMS] = {
    bitmap_icon_wifi,
    bitmap_icon_antenna,
    bitmap_icon_wifi_jammer,
    bitmap_icon_Skull_3,
    bitmap_icon_eye2,
    bitmap_icon_jammer,
    bitmap_icon_bash,
    bitmap_icon_eye_blind,
    bitmap_icon_key,
    bitmap_icon_list,
    bitmap_icon_devil,
    bitmap_icon_go_back
};

const unsigned char *wifi_page0_icons[WIFI_PAGE0_FEATURES] = {
    bitmap_icon_wifi,
    bitmap_icon_antenna,
    bitmap_icon_wifi_jammer,
    bitmap_icon_Skull_3,
    bitmap_icon_eye2,
    bitmap_icon_jammer,
    bitmap_icon_bash,
    bitmap_icon_eye_blind
};

const unsigned char *wifi_page1_icons[WIFI_PAGE1_FEATURES] = {
    bitmap_icon_key,
    bitmap_icon_list,
    bitmap_icon_devil
};

const unsigned char *bluetooth_page0_icons[BT_PAGE0_FEATURES] = {
    bitmap_icon_ble_jammer,
    bitmap_icon_spoofer,
    bitmap_icon_apple,
    bitmap_icon_tags,
    bitmap_icon_magnifying_glass,
    bitmap_icon_analyzer,
    bitmap_icon_graph,
    bitmap_icon_rubber_ducky
};

const unsigned char *bluetooth_page1_icons[BT_PAGE1_FEATURES] = {
    bitmap_icon_Wireless_4
};

const unsigned char *nrf_submenu_icons[nrf_NUM_SUBMENU_ITEMS] = {
    bitmap_icon_scanner,
    bitmap_icon_kill,
    bitmap_icon_analyzer,
    bitmap_icon_follow,
    bitmap_icon_magnifying_glass,
    bitmap_icon_key,
    bitmap_icon_go_back
};

const unsigned char *subghz_submenu_icons[subghz_NUM_SUBMENU_ITEMS] = {
    bitmap_icon_antenna,
    bitmap_icon_no_signal,
    bitmap_icon_graph_self_loop,
    bitmap_icon_Voice_Id,
    bitmap_icon_list,
    bitmap_icon_go_back
};

const unsigned char *tools_submenu_icons[tools_NUM_SUBMENU_ITEMS] = {
    bitmap_icon_bash,
    bitmap_icon_follow,
    bitmap_icon_undo,
    bitmap_icon_sdcard,
    bitmap_icon_go_back
};

const unsigned char *other_submenu_icons[other_NUM_SUBMENU_ITEMS] = {
    bitmap_icon_led,
    bitmap_icon_rfid_chip,
    bitmap_icon_satellite,
    bitmap_icon_go_back
};

const unsigned char *rfid_submenu_icons[rfid_NUM_SUBMENU_ITEMS] = {
    bitmap_icon_magnifying_glass,
    bitmap_icon_follow,
    bitmap_icon_recycle,
    bitmap_icon_dot_matrix,
    bitmap_icon_key,
    bitmap_icon_kill,
    bitmap_icon_flash,
    bitmap_icon_devil,
    bitmap_icon_go_back
};

const unsigned char *gps_submenu_icons[gps_NUM_SUBMENU_ITEMS] = {
    bitmap_icon_satellite,
    bitmap_icon_satellite_dish,
    bitmap_icon_go_back
};

const unsigned char *ir_submenu_icons[ir_NUM_SUBMENU_ITEMS] = {
    bitmap_icon_led,
    bitmap_icon_list,
    bitmap_icon_remote_control,
    bitmap_icon_go_back
};

const unsigned char *about_submenu_icons[about_NUM_SUBMENU_ITEMS] = {
    bitmap_icon_go_back
};

const unsigned char *setting_submenu_icons[setting_NUM_SUBMENU_ITEMS] = {
    bitmap_icon_go_back
};

const unsigned char **active_submenu_icons = nullptr;

static int wifiFeatureCount() {
    return (wifi_submenu_page == 0) ? WIFI_PAGE0_FEATURES : WIFI_PAGE1_FEATURES;
}

static int bluetoothFeatureCount() {
    return (bluetooth_submenu_page == 0) ? BT_PAGE0_FEATURES : BT_PAGE1_FEATURES;
}

static int pagedFeatureCount() {
    if (current_menu_index == 4) {
        return bluetoothFeatureCount();
    }
    return wifiFeatureCount();
}

static int* pagedSubmenuPage() {
    return (current_menu_index == 4) ? &bluetooth_submenu_page : &wifi_submenu_page;
}

// Bottom row: [icon | Main Menu] ........ [Next/Prev Page | icon]
static int pagedBackBtnIndex() {
    return pagedFeatureCount();
}

static int pagedPageBtnIndex() {
    return pagedFeatureCount() + 1;
}

static int pagedNavRowY() {
    return tft.height() - 30;
}

static const char* pagedPageBtnLabel() {
    return (*pagedSubmenuPage() == 0) ? "Next Page" : "Prev Page";
}

static const unsigned char* pagedPageBtnIcon() {
    return (*pagedSubmenuPage() == 0) ? bitmap_icon_navigate_right : bitmap_icon_navigate_left;
}

static void layoutPagedFooterButtons() {
    const int y = pagedNavRowY();
    const int mid = tft.width() / 2;
    s_pagedFooterBtns[0] = {
        0, (int16_t)y, (int16_t)mid, 28,
        "Main Menu", FeatureUI::ButtonStyle::Secondary, false};
    s_pagedFooterBtns[1] = {
        (int16_t)mid, (int16_t)y, (int16_t)(tft.width() - mid), 28,
        pagedPageBtnLabel(), FeatureUI::ButtonStyle::Secondary, false};
}

static void drawPagedFooterButtons() {
    layoutPagedFooterButtons();
    const int y = pagedNavRowY();
    const int rowH = 28;
    const int iconSize = 16;
    tft.fillRect(0, y, tft.width(), rowH, UI_BG);

    tft.setTextDatum(TL_DATUM);
    tft.setTextFont(2);
    tft.setTextSize(1);
    // Font 2 is ~16px; center icon + text on the same midline within the row.
    const int textH = 16;
    const int iconY = y + (rowH - iconSize) / 2;
    const int textY = y + (rowH - textH) / 2;

    {
        const uint16_t color = (s_pagedFooterFocus == 0) ? UI_ICON : UI_TEXT;
        tft.setTextColor(color, UI_BG);
        tft.drawBitmap(10, iconY, bitmap_icon_go_back, iconSize, iconSize, color);
        tft.setCursor(30, textY);
        tft.print("Main Menu");
    }

    {
        const uint16_t color = (s_pagedFooterFocus == 1) ? UI_ICON : UI_TEXT;
        const char* label = pagedPageBtnLabel();
        const int gap = 4;
        const int textW = tft.textWidth(label);
        // Right-aligned group: [label][gap][icon] — same vertical midline.
        const int iconX = tft.width() - 10 - iconSize;
        const int textX = iconX - gap - textW;
        tft.setTextColor(color, UI_BG);
        tft.setCursor(textX, textY);
        tft.print(label);
        tft.drawBitmap(iconX, iconY, pagedPageBtnIcon(), iconSize, iconSize, color);
    }
}

static void applyWifiSubmenuPage() {
    if (wifi_submenu_page == 0) {
        active_submenu_items = wifi_page0_items;
        active_submenu_icons = wifi_page0_icons;
    } else {
        active_submenu_items = wifi_page1_items;
        active_submenu_icons = wifi_page1_icons;
    }
    active_submenu_size = wifiFeatureCount() + 2;
    if (current_submenu_index >= active_submenu_size) {
        current_submenu_index = 0;
    }
    s_pagedFooterFocus = -1;
    last_submenu_index = -1;
    submenu_initialized = false;
}

static void applyBluetoothSubmenuPage() {
    if (bluetooth_submenu_page == 0) {
        active_submenu_items = bluetooth_page0_items;
        active_submenu_icons = bluetooth_page0_icons;
    } else {
        active_submenu_items = bluetooth_page1_items;
        active_submenu_icons = bluetooth_page1_icons;
    }
    active_submenu_size = bluetoothFeatureCount() + 2;
    if (current_submenu_index >= active_submenu_size) {
        current_submenu_index = 0;
    }
    s_pagedFooterFocus = -1;
    last_submenu_index = -1;
    submenu_initialized = false;
}

void updateActiveSubmenu() {
    switch (current_menu_index) {
        case 0:
            wifi_submenu_page = 0;
            current_submenu_index = 0;
            applyWifiSubmenuPage();
            break;
        case 1:
            active_submenu_items = nrf_submenu_items;
            active_submenu_size = nrf_NUM_SUBMENU_ITEMS;
            active_submenu_icons = nrf_submenu_icons;
            break;
        case 2:
            if (other_layer == OTHER_LAYER_HOME) {
                active_submenu_items = other_submenu_items;
                active_submenu_size = other_NUM_SUBMENU_ITEMS;
                active_submenu_icons = other_submenu_icons;
            } else if (other_layer == OTHER_LAYER_IR) {
                active_submenu_items = ir_submenu_items;
                active_submenu_size = ir_NUM_SUBMENU_ITEMS;
                active_submenu_icons = ir_submenu_icons;
            } else if (other_layer == OTHER_LAYER_RFID) {
                active_submenu_items = rfid_submenu_items;
                active_submenu_size = rfid_NUM_SUBMENU_ITEMS;
                active_submenu_icons = rfid_submenu_icons;
            } else if (other_layer == OTHER_LAYER_GPS) {
                active_submenu_items = gps_submenu_items;
                active_submenu_size = gps_NUM_SUBMENU_ITEMS;
                active_submenu_icons = gps_submenu_icons;
            } else {
                active_submenu_items = other_submenu_items;
                active_submenu_size = other_NUM_SUBMENU_ITEMS;
                active_submenu_icons = other_submenu_icons;
            }
            break;
        case 3:
            active_submenu_items = nullptr;
            active_submenu_size = 0;
            active_submenu_icons = nullptr;
            break;
        case 4:
            bluetooth_submenu_page = 0;
            current_submenu_index = 0;
            applyBluetoothSubmenuPage();
            break;
        case 5:
            active_submenu_items = subghz_submenu_items;
            active_submenu_size = subghz_NUM_SUBMENU_ITEMS;
            active_submenu_icons = subghz_submenu_icons;
            break;
        case 6:
            active_submenu_items = tools_submenu_items;
            active_submenu_size = tools_NUM_SUBMENU_ITEMS;
            active_submenu_icons = tools_submenu_icons;
            break;
        case 7:
            active_submenu_items = nullptr;
            active_submenu_size = 0;
            active_submenu_icons = nullptr;
            break;

        default:
            active_submenu_items = nullptr;
            active_submenu_size = 0;
            active_submenu_icons = nullptr;
            break;
    }
}

static bool touchButtonInputEnabled = false;
static bool touchButtonCueDrawn = false;
static bool s_touchNavLabelsConfigured = false;
static bool s_touchNavHeld[5] = {false, false, false, false, false};
#if HAS_PCF8574_BUTTONS
static bool s_pcfButtonLastState[8] = {true, true, true, true, true, true, true, true};
#endif
static FeatureUI::Button s_touchNavBtns[5];
static const char* s_touchNavLabels[5] = {nullptr, nullptr, nullptr, nullptr, nullptr};
static constexpr int16_t TOUCH_NAV_BAR_H = (FeatureUI::FOOTER_H * 4) / 5;  // 20% shorter than footer

static int touchNavPinForIndex(int idx) {
  switch (idx) {
    case 0: return BTN_LEFT;
    case 1: return BTN_DOWN;
    case 2: return BTN_SELECT;
    case 3: return BTN_UP;
    case 4: return BTN_RIGHT;
    default: return -1;
  }
}

void setTouchButtonInputEnabled(bool enabled) {
  if (touchButtonInputEnabled != enabled) {
    touchButtonCueDrawn = false;
    if (!enabled) {
      for (int i = 0; i < 5; ++i) {
        s_touchNavLabels[i] = nullptr;
      }
      s_touchNavLabelsConfigured = false;
      for (int i = 0; i < 5; ++i) {
        s_touchNavHeld[i] = false;
      }
    }
  }
  touchButtonInputEnabled = enabled;
#if TOUCH_BUTTON_CUE_ENABLED
  if (enabled && feature_active) {
    drawTouchNavBar();
    touchButtonCueDrawn = true;
  }
#endif
}

bool featureHasTouchNavBar() {
#if TOUCH_BUTTON_CUE_ENABLED
  return touchButtonInputEnabled && feature_active;
#else
  return false;
#endif
}

void setTouchNavLabels(const char* left, const char* down, const char* center,
                       const char* up, const char* right) {
  s_touchNavLabels[0] = left;
  s_touchNavLabels[1] = down;
  s_touchNavLabels[2] = center;
  s_touchNavLabels[3] = up;
  s_touchNavLabels[4] = right;
  s_touchNavLabelsConfigured = true;
  invalidateTouchButtonCue();
}

void invalidateTouchButtonCue() {
  touchButtonCueDrawn = false;
}

void resetTouchNavHeldState() {
  for (int i = 0; i < 5; ++i) {
    s_touchNavHeld[i] = false;
  }
}

void redrawTouchButtonBar() {
  invalidateTouchButtonCue();
  drawTouchButtonCue();
}

static void layoutTouchNavBtns() {
  const int barY = tft.height() - TOUCH_NAV_BAR_H;
  const int barH = TOUCH_NAV_BAR_H;
  const int totalW = tft.width();
  const int cellW = totalW / 5;

  for (int i = 0; i < 5; ++i) {
    const int x = i * cellW;
    const int w = (i == 4) ? (totalW - x) : cellW;
    s_touchNavBtns[i] = {
      (int16_t)x, (int16_t)barY, (int16_t)w, (int16_t)barH,
      nullptr, FeatureUI::ButtonStyle::Secondary, false};
  }
}

static String fitTouchNavLabel(const char* label, int maxWidth) {
  if (!label || !label[0]) {
    return String();
  }
  String out = label;
  if (tft.textWidth(out) <= maxWidth) {
    return out;
  }
  while (out.length() > 1 && tft.textWidth(out + "...") > maxWidth) {
    out.remove(out.length() - 1);
  }
  return out + "...";
}

static void drawTouchNavBar() {
  static const unsigned char* kIcons[5] = {
    bitmap_icon_LEFT,
    bitmap_icon_DOWN,
    bitmap_icon_go_back,
    bitmap_icon_UP,
    bitmap_icon_RIGHT,
  };
  constexpr int kIconSize = 16;

  const int barY = tft.height() - TOUCH_NAV_BAR_H;
  const int barH = TOUCH_NAV_BAR_H;
  const int barW = tft.width();

  layoutTouchNavBtns();

  tft.fillRect(0, barY, barW, barH, UI_FG);
  tft.drawFastHLine(0, barY, barW, UI_LINE);

  for (int i = 0; i < 5; ++i) {
    const auto& b = s_touchNavBtns[i];
    if (i > 0) {
      tft.drawFastVLine(b.x, barY + 3, barH - 6, UI_LINE);
    }

    if (s_touchNavLabels[i] && s_touchNavLabels[i][0]) {
      tft.setTextDatum(MC_DATUM);
      const uint16_t txtColor = (i == 2) ? UI_ICON : UI_TEXT;
      tft.setTextColor(txtColor, UI_FG);
      const String fit = fitTouchNavLabel(s_touchNavLabels[i], b.w - 8);
      tft.drawString(fit, b.x + b.w / 2, b.y + b.h / 2, 1);
    } else {
      const int ix = b.x + (b.w - kIconSize) / 2;
      const int iy = b.y + (b.h - kIconSize) / 2;
      const bool inactiveSlot = s_touchNavLabelsConfigured && !s_touchNavLabels[i];
      const unsigned char* icon = inactiveSlot ? bitmap_icon_dots : kIcons[i];
      const uint16_t iconColor = inactiveSlot ? LIGHT_GRAY : ((i == 2) ? UI_ICON : UI_TEXT);
      tft.drawBitmap(ix, iy, icon, kIconSize, kIconSize, iconColor);
    }
  }

  tft.setTextDatum(TL_DATUM);
  tft.setTextFont(1);
  tft.setTextSize(1);
  tft.setTextColor(UI_TEXT, FEATURE_BG);
}

void maintainTouchNavBar() {
#if TOUCH_BUTTON_CUE_ENABLED
  if (!touchButtonInputEnabled || !feature_active || touchButtonCueDrawn) {
    return;
  }
  drawTouchNavBar();
  touchButtonCueDrawn = true;
#endif
}

void featureClearContent(uint16_t color) {
  const int bottom = touchNavContentBottomY();
  if (bottom > 0) {
    tft.fillRect(0, 0, tft.width(), bottom, color);
  } else {
    tft.fillScreen(color);
  }
}

int16_t touchNavReservedHeight() {
#if TOUCH_BUTTON_CUE_ENABLED
  if (touchButtonInputEnabled && feature_active) {
    return TOUCH_NAV_BAR_H;
  }
#endif
  return 0;
}

int16_t touchNavContentBottomY() {
  return (int16_t)(tft.height() - touchNavReservedHeight());
}

void drawTouchButtonCue() {
#if TOUCH_BUTTON_CUE_ENABLED
  if (!touchButtonInputEnabled || !feature_active) {
    return;
  }
  drawTouchNavBar();
  touchButtonCueDrawn = true;
#endif
}

static int touchNavIndexForPin(int buttonPin) {
  for (int i = 0; i < 5; ++i) {
    if (touchNavPinForIndex(i) == buttonPin) {
      return i;
    }
  }
  return -1;
}
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
void loop() {
  // MERGE: RGB status LED (GPIO48). Toggle via Settings > NeoPixel.
  //   OFF when disabled. Otherwise shows battery charge when a real battery
  //   is detected, else green = running. Reuses currentBatteryVoltage (no
  //   extra ADC read). Battery sensing needs BATTERY_ADC_PIN set + a 2:1
  //   divider; charging-vs-full is NOT detectable without a CHG-status pin.
  // REWIRE 2026-09-23: disabled — GPIO48 is now the TFT/Touch MISO line.
#ifndef BOARD_NO_STATUS_RGB
  {
    static int lastColor = -2;   // -1 off, 0 red, 1 yellow, 2 blue, 3 green
    int color;
    if (!settings().neopixelEnabled) {
      color = -1;
    } else {
      float v = currentBatteryVoltage;
      if (v >= 2.8f && v <= 4.35f) {             // real battery present
        int pct = constrain((int)((v - 3.0f) / 1.2f * 100.f), 0, 100);
        if      (pct < 20) color = 0;   // red    = low
        else if (pct < 50) color = 1;   // yellow = partial
        else if (pct < 85) color = 2;   // blue   = half+
        else               color = 3;   // green  = full
      } else {
        color = 3;                                // USB / no battery -> green
      }
    }
    if (color != lastColor) {
      switch (color) {
        case -1: neopixelWrite(RGB_BUILTIN, 0,  0,  0);  break;  // off
        case 0:  neopixelWrite(RGB_BUILTIN, 40, 0,  0);  break;  // red
        case 1:  neopixelWrite(RGB_BUILTIN, 34, 22, 0);  break;  // yellow
        case 2:  neopixelWrite(RGB_BUILTIN, 0,  10, 40); break;  // blue
        default: neopixelWrite(RGB_BUILTIN, 0,  14, 0);  break;  // green
      }
      lastColor = color;
    }
  }
#endif // BOARD_NO_STATUS_RGB

  applyThemeToPalette(settings().theme);
  handleButtons();
  updateStatusBar();
}

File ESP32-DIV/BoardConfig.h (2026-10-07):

#pragma once

/* =====================================================================
   ESP32-S3 DevKitC-1  N16R8  — bare DevKit port
   =====================================================================

   Upstream ESP32-DIV V2 targets an ESP32-S3-WROOM-1U-N16: 16MB flash and
   NO PSRAM. That is why its stock pin map puts the display and touch bus on
   GPIO 35/36/37 — with no PSRAM die in the package those pins are free.

   This board is an N16R8: 16MB flash plus 8MB *octal* PSRAM. Octal PSRAM is
   bonded to GPIO 33-37 inside the module, so those five pins do not exist as
   GPIO here. Keeping the 8MB means the display bus must move.

   Everything below is an override of an #ifndef in shared.h, which includes
   this file first. Upstream sources stay untouched except for two small,
   clearly marked edits (see PORT.md).

   Build with PSRAM = OPI PSRAM. See PORT.md for the full IDE settings.
   ===================================================================== */

/* Keep the V2 target: it selects BOARD_HAS_ESP32S3 and the S3 code paths.
   Only the pin assignments differ. */
#define BOARD_ESP32_DIV_V2

#define ESP32DIV_BOARD_NAME "S3 DevKit N16R8"

/* ---------------------------------------------------------------------
   Input: the KY-023 analog joystick stands in for the PCF8574 keypad.
   JoystickNav.h exposes the same pinMode/digitalRead API the features
   already call, so no feature code changes. Verified working on 4/5/6.
   --------------------------------------------------------------------- */
#define HAS_PCF8574_BUTTONS 1
#define USE_JOYSTICK_NAV    1

#define JOY_X_PIN   4     /* VRX — ADC1_CH3 */
#define JOY_Y_PIN   5     /* VRY — ADC1_CH4 */
#define JOY_SW_PIN  6     /* SW  — INPUT_PULLUP */

/* Deflection from centre before a direction latches (12-bit ADC). */
#define JOY_DEADZONE 700

/* ---------------------------------------------------------------------
   Shared SPI bus — SD + display + touch + CC1101 + PN532
   These three are this board's verified MicroSD wiring. Every other
   device on this bus adds only its own chip select.
   --------------------------------------------------------------------- */
#define SD_MOSI  11
#define SD_SCLK  12
#define SD_MISO  13
#define SD_CS    10

/* The generic MicroSD breakout has no card-detect switch. This makes
   shared.h skip SD_CD entirely, so utils.cpp takes its "assume present"
   path instead of reading a floating pin. */
#define SD_NO_CARD_DETECT 1

/* ---------------------------------------------------------------------
   Display + touch (ILI9341 + XPT2046) — moved off the PSRAM pins.
   MOSI/SCLK/MISO are the shared bus above; these are the control lines.
   TFT_eSPI needs matching values in its own User_Setup.h — PORT.md
   documents the edit, and it is already applied.
   --------------------------------------------------------------------- */
/* REWIRE 2026-09-23: display + touch moved onto their OWN SPI bus.
   TFT/Touch:  MOSI=15  SCLK=47  MISO=48 (these three live in TFT_eSPI's
   User_Setup.h; the control lines below must match it). */
#define TFT_MOSI_PIN    15
#define TFT_SCLK_PIN    47
#define TFT_MISO_PIN    48
#define TFT_CS_PIN      39   /* REWIRE: TFT CS on 39 (USB-safe; moved off GPIO20 = native USB D+) */
#define TFT_DC_PIN       9   /* REWIRE: was 40 */
#define TFT_RST_PIN      8   /* REWIRE: was 41 */
/* TPM408-2.8 bench panel (see ILI9341_NATIVE_LANDSCAPE_PANEL in TFT_eSPI's
   User_Setup.h): 0 = portrait, pin header at the bottom; 2 = header at top. */
#define TFT_ROTATION     0
#define BACKLIGHT_PIN   -1   /* LED is hard-wired to 3V3. GPIO42 is now PN532 MISO. */

/* GPIO48 is now the TFT/Touch MISO line, so the onboard WS2812 status LED
   cannot be used. This disables the neopixelWrite() calls in ESP32-DIV.ino. */
#define BOARD_NO_STATUS_RGB 1

/* Touch rides the display's SPI bus via TFT_eSPI's getTouchRaw(), so it
   costs one chip select rather than a second bus. */
#define TOUCH_SHARES_TFT_SPI 1
#define XPT2046_CS   45          /* REWIRE: T_CS (was 38) */
#define XPT2046_MOSI TFT_MOSI_PIN /* REWIRE: touch shares the TFT bus (15/47/48), not SD */
#define XPT2046_MISO TFT_MISO_PIN
#define XPT2046_CLK  TFT_SCLK_PIN
#define XPT2046_IRQ  46          /* REWIRE: T_IRQ now wired to 46; still polled in shared-SPI mode */

/* ---------------------------------------------------------------------
   NRF24L01+ — this board's verified wiring on a SECOND SPI bus.
   Upstream V2 shares the SD bus; here the radio keeps its own pins, which
   avoids the classic problem of cheap SD modules not releasing MISO.
   Verified: register round-trip and TX_ADDR = E7 E7 E7 E7 E7.
   --------------------------------------------------------------------- */
#define NRF24_SPI_SCK  17
#define NRF24_SPI_MOSI 18
#define NRF24_SPI_MISO 21
#define NRF24_SPI_SS    7

#define CE_PIN_1   16
#define CSN_PIN_1   7
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

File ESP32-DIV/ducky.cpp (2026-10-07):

#include <Arduino.h>
#include <NimBLEDevice.h>
#include <NimBLEHIDDevice.h>
#include <PCF8574.h>
#include <SD.h>
#include <SPI.h>
#include <TFT_eSPI.h>
#include <vector>
#include "Touchscreen.h"
#include "icon.h"
#include "shared.h"
#include "utils.h"

extern NavExpander pcf;

extern bool feature_exit_requested;

extern TFT_eSPI tft;

#ifdef TFT_BLACK
#undef TFT_BLACK
#endif
#define TFT_BLACK FEATURE_BG

#ifndef FEATURE_TEXT
#define FEATURE_TEXT ORANGE
#endif
#ifndef FEATURE_WHITE
#define FEATURE_WHITE 0xFFFF
#endif

#ifdef TFT_WHITE
#undef TFT_WHITE
#endif
#define TFT_WHITE FEATURE_TEXT

#ifdef WHITE
#undef WHITE
#endif
#define WHITE FEATURE_WHITE

#ifdef DARK_GRAY
#undef DARK_GRAY
#endif
#define DARK_GRAY UI_FG

namespace Ducky {

static const char* DUCKY_DIR = "/ducky";
static const char* DEV_NAME  = "ESP32S3 Ducky";

#define COL_BG     TFT_BLACK
#define COL_FG     TFT_WHITE
#define COL_ACCENT FEATURE_TEXT
#define COL_WARN   UI_WARN
#define COL_ROWSEL L_Dark

static const int HEADER_H    = 20;

static const int TEXT_HEADER_H = HEADER_H;
static const int FOOTER_H    = FeatureUI::FOOTER_H;
static const int BTN_H       = FeatureUI::BTN_H;
static const int BTN_GAP     = FeatureUI::GAP_X;

static const int LIST_ROW_H  = 40;

static const int LIST_ROW_GAP = 6;
static const int PADDING     = FeatureUI::PAD_X;

static const int TOOLBAR_Y      = 37;
static const int TOOLBAR_HEIGHT = HEADER_H;

static int duckyFooterReserve() {
  return featureHasTouchNavBar() ? touchNavReservedHeight() : FOOTER_H;
}

static int duckyToastTop() {
  return DISPLAY_HEIGHT - duckyFooterReserve() - 28;
}

static int duckyToastCenterY() {
  return DISPLAY_HEIGHT - duckyFooterReserve() - 24;
}

static bool sd_mounted = false;
static bool ui_inited  = false;
static bool ui_busy    = false;
static bool needsRedraw = false;

static bool ducky_active = false;

struct EdgeBtn {
  uint8_t pin;
  bool last;
  uint32_t tLast;
  EdgeBtn(): pin(0), last(true), tLast(0) {}
  explicit EdgeBtn(uint8_t p): pin(p), last(true), tLast(0) {}
};

static EdgeBtn ebUp{BTN_UP}, ebDown{BTN_DOWN}, ebLeft{BTN_LEFT}, ebRight{BTN_RIGHT}, ebSelect{BTN_SELECT};

static bool uiDrawn = false;
static unsigned long lastAnimationTime = 0;
static int animationState = 0;
static int activeIcon = -1;

static const int ICON_NUM = 2;
static int iconX[ICON_NUM] = {210, 10};
static int iconY = 20;

static const unsigned char* icons[ICON_NUM] = {
    bitmap_icon_list,
    bitmap_icon_go_back
};

static const int ICON_SIZE = 16;

static bool pcfPressedEdge(EdgeBtn& eb, uint16_t debounceMs=40) {
  bool cur = isButtonPressed(eb.pin) ? LOW : HIGH;
  uint32_t now = millis();
  bool pressedEvent = (!cur && eb.last && (now - eb.tLast) > debounceMs);
  if (pressedEvent) eb.tLast = now;
  eb.last = cur;
  return pressedEvent;
}

static NimBLEHIDDevice*      hid = nullptr;
static NimBLECharacteristic* inputChr = nullptr;
static NimBLECharacteristic* outputChr = nullptr;
static volatile bool         bleConnected = false;

struct ScriptItem { String path, name, desc; uint32_t size = 0; };
static std::vector<ScriptItem> items;
static int  sel = 0;

enum class Page { List, Details, Settings };
static Page page = Page::List;

static void duckyUpdateNavLabels() {
  if (!featureHasTouchNavBar()) {
    return;
  }
  if (page == Page::List) {
    setTouchNavLabels("Exit", "Reload", "Open", "Prev", "Next");
  } else if (page == Page::Details) {
    setTouchNavLabels("Back", "Delete", "Run", "List", "Run");
  } else if (page == Page::Settings) {
    setTouchNavLabels("Back", "Reload", "Open", "Prev", "Next");
  }
  redrawTouchButtonBar();
}

enum class Dialog { None, ConfirmDelete };
static Dialog dialog = Dialog::None;

static uint32_t defaultDelay = 0;
static String   lastError;

static String trimCR(const String& s) {
  String x = s; if (x.endsWith("\r")) x.remove(x.length() - 1); return x;
}
static void clampSel() {
  int last = (int)items.size() - 1; if (last < 0) last = 0;
  if (sel > last) sel = last; if (sel < 0) sel = 0;
}
static String fitText(const String& s, int pixWidth, int font = 2) {
  String out = s;
  while (tft.textWidth(out, font) > pixWidth && out.length() > 1) {
    out.remove(out.length() - 1);
  }
  if (out.length() < s.length() && pixWidth >= tft.textWidth("…", font) + 4) out += "…";
  return out;
}

static int wrapLineNoEllipsis(const String& s, int pixWidth, int font, String& outLine) {
  if (s.length() == 0) { outLine = ""; return 0; }

  int nl = s.indexOf('\n');
  if (nl >= 0) {
    String pre = s.substring(0, nl);
    if (tft.textWidth(pre, font) <= pixWidth) {
      outLine = pre;
      outLine.trim();
      return nl + 1;
    }
  }

  int best = 0;
  int len = (int)s.length();
  for (int i = 1; i <= len; i++) {
    String sub = s.substring(0, i);
    if (tft.textWidth(sub, font) <= pixWidth) best = i;
    else break;
  }
  if (best <= 0) best = 1;

  int breakAt = best;
  int lastSpace = -1;
  for (int i = best - 1; i >= 0; i--) {
    if (s[i] == ' ') { lastSpace = i; break; }
  }
  if (lastSpace > 0) {
    const int tail = best - lastSpace;

    if (tail <= 12) breakAt = lastSpace;
  }
  if (breakAt <= 0) breakAt = best;

  outLine = s.substring(0, breakAt);
  outLine.trim();
  return breakAt;
}

struct Tap {
  bool has = false;
  int  x = 0, y = 0;
  unsigned long time = 0;
};
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

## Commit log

2026-10-07 Initial release: rkstlohchab firmware, hardware wiring and enclosure
    [ESPDIV-v1 pcb.PcbDoc, ESPDIV-v1 schematic.SchDoc, ESPDIV.PrjPcb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]
2026-10-07 Label breadboard shared nets in wiring diagrams
2026-10-07 Draw actual breadboard wiring paths and document assembly mistakes
    [generate_wiring.py]
2026-10-07 Add illustrated wiring poster using enclosure component models
